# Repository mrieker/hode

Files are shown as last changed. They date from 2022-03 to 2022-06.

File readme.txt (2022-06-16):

        HODE 16-BIT TRANSISTOR COMPUTER

Website:  https://www.outerworldapps.com/hode

Uses a RaspberryPi for memory and IO (not needed for simulator).
Requires a Linux computer (x86 or raspi) to build software.
KiCad used to do PCB layouts.
Must have GNU C++ compiler, Java 8 or better dev kit.

Directories:

    asm      - cross assembler and linker
                $ make

    cc       - cross compiler
                $ make

    crtl     - C runtime library and example programs
                # make asm, cc, driver first
                $ cd library
                $ make
                $ cd ..
                $ make
                $ ./runit.sh circus.hex < test01.circ   ## runs in simlator (x86 or arm, no hode hardware required)
                $ ./runhw.sh circus.hex < test01.circ   ## runs on hode hardware that this raspi is plugged into

    de0      - DE0-Nano FPGA implementation (in verilog)
               requires de0-nano board, raspberry pi, kicads/de0raspi interconnect board
               use quartus to compile verilog in the de0 directory and program the de0-nano
               populate interconnect board with two 2x20 connectors and 26 33-ohm resistors
               plug raspi into the raspi connector and de0-nano gpio 1 into the de0 connector
               should be able to run any hode programs such as:

                # desktop calculator
                $ cd crtl
                $ ./runhw.sh calc.hex

                # rolling lights
                $ cd driver
                $ ./raspictl rollights.hex

    driver   - raspi control program and hardware test programs
                $ make
                $ cd km
                $ make                      ## on raspi only
                $ sudo insmod enabtsc.ko    ## on raspi only

                    note:  hexfile.hex is a placeholder for an actual hex file (see crtl directory)

                $ ./raspictl.armv7l       hexfile.hex   ## runs hexfile.hex on attached hode hardware
                                                        ## runs until hexfile.hex program calls exit()

                $ ./raspictl.armv7l -nohw hexfile.hex   ## simulator (no hode hardware required)

                $ ./raspictl.x86_64 -nohw hexfile.hex   ## simulator running on x86

    freecads - case component drawings

    goodpcbs - good pcb files (routing completed, including netlist and parts list files)

    kicads   - other kicad files
                de0raspi - interconnect for de0 nano and raspberry pi
                IOW56Paddle - IO-Warrior-56 paddles for board-level testing
                PowerDist - power distribution board - connects edge power to power supply

    modules  - board modules (verilog-like code)
                # make netgen first
                $ ./testmaster.sh   ## runs regression test scripts
                $ ./pcball.sh       ## generate raw .pcb files, need trace routing via kicad

    netgen   - java program to compile modules for simulation and pcb generation
                # make sure jninc_x86_64 or jninc_armv7l points to directory where jni.h is located
                $ make

For those makefiles that create objects and executables, they will create two versions,
one for x86_64 and one for armv7l, depending on which computer type they are run on.
Typically this is just done for the driver directory, once on a PC (creating the .x86_64
files) and once on a raspi (creating the .armv7l files).  The other directories are
typically only done on the PC but can be done on a raspi (either instead of or as well as).

HOW TO BUILD

    Each board takes a little under 1.5A at 5V * 9 boards = 13.5A + raspi (2.5A) = 16A.
    Get 40 2x20 stackable connectors (and a couple extra).
    Get 9 1x6 pin right angle connectors for power.

    Make the 4 paddles by making the circuit boards, populate with 10K 1/8 watt resistors,
    and get an IOWarrior-56 module for each.  Put a 2x20 stackable connector on each.
    Run drivers/iow56list.armv7l on the raspi to get the serial number for each one at a time.
    Label them A, C, I, D with little stickers and put the serial numbers in netgen/iow56sns.si.

    When populating the main boards, start with the diodes as they are uniquely marked.  Of course
    make sure the bands on the diodes match the bands on the board.  Next do the 2.7K resistors as
    they are among the diodes.  Next come the 680 resistors, they go near the transistor collector
    leads and then the 1K resistors that go near the transistor emitter leads.  Then do the bypass
    capacitors that go next to the transistor collector and emitter leads.  Finally put in the
    transistors then the edge connectors.

    When soldering the 2x20 stackable connectors to the boards, make sure they are mounted tightly
    on the boards so they will mate up when stacking the boards.  Be very careful when pulling the
    boards apart that you do not bend the pins on the stackable connectors.  Rock them little by
    little until each one comes apart.

    Optionally make an ledboard.pcb and populate.  It can be used for diagnostics as it shows the
    state of the bus connector pins.  It can be plugged into the other boards one at a time or in
    any combination.  It is not required for testing as the testing is all done via the paddles, but
    can make it easier to track down any problems.  Be careful to note 3 positions are populated
    with 2N3906s instead of the usual 2N3904s and the LEDs are reversed, as the _IR_WE, _PSW_IECLR,
    _PSW_REB signals are active low.

    Make a seqboard.pcb board and populate with diodes, resistors, capacitors, transistors, LEDs,
    connectors.  Connect to a variable power supply and turn slowly up to 5V, it should draw under
    1.5A.  Plug in the 4 paddles (actually just need C and I paddles).  Run the 'drivers/seqtester
    -cpuhz 200 -loop' script to test it.  The paddles are limited to 200Hz so that's why the '-cpuhz
    200' option is needed.

    Make a rasboard.pcb board and populate as usual.  You will also need a 2x20 connector for the
    raspi and a raspi 3 or 4 to plug into it.  The little 4x4 connector pins near the raspi connector
    jumpers the 5V power from the board's main power to the raspi.  With the jumpers removed, the
    raspi must be powered via its usual USB connector, otherwise the raspi will be powered from the
    board's 5V supply.  Once constructed, leave the raspi off the board and test it with a variable
    power supply like with the seqboard and see that it takes under 1.5A.  Then it should be ok to
    plug the raspi in.  You can use 7/16" spacers on 3/4" 4-40 screws to hold the raspi in place.
    Plug all 4 paddles into the edge of the rasboard and the USB cables into the raspi.  Run the
    'drivers/rastester.sh -cpuhz 200 -loop' script to test it.

    Plug the seqboard and rasboard together.  They should be oriented so the power connectors are at
    same position.  Run the 'drivers/raseqtest.sh -cpuhz 200 -loop' script to test it.  It assumes
    the 4 paddles are plugged in, if not, use the -nopads option on the command line and it will test
    as much as it can without it.  With -nopads, the two boards should run fast, so try leaving off the
    '-cpuhz 200' option.

    Make aluboards one at a time.  Jumper one as hi-byte and use 'drivers/alutester.sh -cpuhz 200 -loop
    hi' to test it with the 4 paddles.  Likewise make a lo-byte board and test it.

    Stack both aluboards and plug into the seqboard/rasboard stack.  Test with all 4 paddles plugged in
    to the stack and the raspi using the 'drivers/raseqtest.sh -alu -cpuhz 200 -loop' command.

    Finally come the register boards.  They can be tested individually with the 'drivers/regtester.sh 
    -cpuhz 200 -loop <nn>' script.  <nn> is 01, 23, 45, 67 depending on how the register board is
    jumpered.  When the board tests ok with the regtester script, it can be added to the seq/ras/alu
    stack and tested with 'drivers/raseqtest.sh -alu -cpuhz 200 -loop -reg<nn>' command.  Use a
    -reg01, -reg23, -reg45, -reg67 option for each register board you have put in the stack.

    When all 8 boards are completed, they can be tested at full speed with the 'drivers/raspictl.armv7l
    -randmem -mintimes' command.  It should run for days and days.  You can experiment with the -cpuhz
    option to specify different clocking frequencies.

    Then you can go to the crtl directory and run a program with the ./runhw.sh script, such as
    './runhw.sh printpi.hex' or './runhw.sh circus.hex < test01.circ'.

    Note that it doesn't matter what order the boards are stacked in, electrically speaking.  You can
    shuffle them around for testing and debugging.  But it is best to put the sequencer board on the
    front when you get it all working so you can see the blinking state LEDs.  If you make the optional
    LED board, it goes in front of the sequencer board and does not block any of the sequencer board's
    LEDs.

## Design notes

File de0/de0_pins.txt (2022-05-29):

    GPIO-0/JP1

    GPIO_0_IN0  A8   1   2  D3  GPIO_0_0
    GPIO_0_IN1  B8   3   4  C3  GPIO_0_1
    GPIO_0_2    A2   5   6  A3  GPIO_0_3
    GPIO_0_4    B3   7   8  B4  GPIO_0_5
    GPIO_0_6    A4   9  10  B5  GPIO_0_7
    VCC_SYS         11  12      GND
    GPIO_0_8    A5  13  14  D5  GPIO_0_9
    GPIO_0_10   B6  15  16  A6  GPIO_0_11
    GPIO_0_12   B7  17  18  D6  GPIO_0_13
    GPIO_0_14   A7  19  20  C6  GPIO_0_15
    GPIO_0_16   C8  21  22  E6  GPIO_0_17
    GPIO_0_18   E7  23  24  D8  GPIO_0_19
    GPIO_0_20   E8  25  26  F8  GPIO_0_21
    GPIO_0_22   F9  27  28  E9  GPIO_0_23
    VCC_3P3         29  30      GND
    GPIO_0_24   C9  31  32  D9  GPIO_0_25
    GPIO_0_26   E11 33  34  E11 GPIO_0_27
    GPIO_0_28   C11 35  36  B11 GPIO_0_29
    GPIO_0_30   A12 37  38  D11 GPIO_0_31
    GPIO_0_32   D12 39  40  B12 GPIO_0_33

    GPIO-1/JP2                                                      RASPI

            GPIO_1_IN0  T9   1   2  F13 GPIO_1_0    write           _qena   GPIO_21 40  39  GND
            GPIO_1_IN1  R9   3   4  T15 GPIO_1_1    m[15]           intrq   GPIO_20 38  37  GPIO_26 write
    _qena   GPIO_1_2    T14  5   6  T13 GPIO_1_3    m[09]           m[12]   GPIO_16 36  35  GPIO_19 m[15]
    intrq   GPIO_1_4    R13  7   8  T12 GPIO_1_5    m[02]                   GND     34  33  GPIO_13 m[09]
    m[12]   GPIO_1_6    R12  9  10  T11 GPIO_1_7    m[01]           m[08]   GPIO_12 32  31  GPIO_6  m[02]
            VCC_SYS         11  12      GND                                 GND     30  29  GPIO_5  m[01]
    m[08]   GPIO_1_8    T10 13  14  R11 GPIO_1_9                            ID_SC   28  27  ID_SD
    m[03]   GPIO_1_10   P11 15  16  R10 GPIO_1_11                   m[03]   GPIO_7  26  25  GND
    m[04]   GPIO_1_12   N12 17  18  P9  GPIO_1_13   m[07]           m[04]   GPIO_8  24  23  GPIO_11 m[07]
    read    GPIO_1_14   N9  19  20  N11 GPIO_1_15   m[05]           read    GPIO_25 22  21  GPIO_9  m[05]
            GPIO_1_16   L16 21  22  K16 GPIO_1_17   m[06]                   GND     20  19  GPIO_10 m[06]
    halt    GPIO_1_18   R16 23  24  L15 GPIO_1_19   dena            halt    GPIO_24 18  17  3.3V
    word    GPIO_1_20   P15 25  26  P16 GPIO_1_21   flag            word    GPIO_23 16  15  GPIO_22 dena
            GPIO_1_22   R14 27  28  N16 GPIO_1_23   m[13]                   GND     14  13  GPIO_27 flag
            VCC_3P3         29  30      GND                         m[14]   GPIO_18 12  11  GPIO_17 m[13]
    m[14]   GPIO_1_24   N15 31  32  P14 GPIO_1_25                   m[11]   GPIO_15 10   9  GND
    m[11]   GPIO_1_26   L14 33  34  N14 GPIO_1_27   m[00]           m[10]   GPIO_14  8   7  GPIO_4  m[00]
    m[10]   GPIO_1_28   M10 35  36  L13 GPIO_1_29   reset                   GND      6   5  GPIO_3  reset
            GPIO_1_30   J16 37  38  K15 GPIO_1_31   clock                   5V       4   3  GPIO_2  clock
            GPIO_1_32   J13 39  40  J14 GPIO_1_33                           5V       2   1  3.3V

                                         CLK    CS   RES   GND   3.3
                                           *     *     *     *     *
                                           6     7     8     9    10

                                                    OLIMEX
                                                  ENC28J60-H

                                           5     4     3     2     1
                                           *     *     *     *     *
                                         INT   WOL    SO    SI   SCK

                                      PIN_D9   E10   B11   D11   B12
                                    GPIO_025   027   029   031   033
                GND                GND   INT   CLK    CS   RES    COMRCV
 2               12                 30    32    34    36    38    40
 *                *                  *     *     *     *     *     *

 *                *                  *     *     *     *     *     *
 1               11                 29    31    33    35    37    39
                +5V               +3.3   WOL    SO    SI   SCK    COMXMT
                                    GPIO_024   026   028   030   032
                                      PIN_C9   E11   C11   A12   D12

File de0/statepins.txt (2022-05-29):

halt state pin:

    fetch1q -> STATES[07] -> PIN_B5 -> GPIO_0_7  -> pin 10
    fetch2q -> STATES[08] -> PIN_A5 -> GPIO_0_8  -> pin 13
    halt1q  -> STATES[17] -> PIN_E6 -> GPIO_0_17 -> pin 22

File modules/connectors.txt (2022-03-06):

    abbus: Conn
         1  oo      abus[00]    bbus[00]
         3  oo      abus[08]    bbus[08]
         5  go                  abus[01]
         7  oo      bbus[01]    abus[09]
         9  go                  bbus[09]
        11  oo      abus[02]    bbus[02]
        13  go                  abus[10]
        15  oo      bbus[10]    abus[03]
        17  go                  bbus[03]
        19  oo      abus[11]    bbus[11]
        21  oo      abus[04]    bbus[04]
        23  go                  abus[12]
        25  oo      bbus[12]    abus[05]
        27  go                  bbus[05]
        29  oo      abus[13]    bbus[13]
        31  go                  abus[06]
        33  oo      bbus[06]    abus[14]
        35  go                  bbus[14]
        37  oo      abus[07]    bbus[07]
        39  oo      abus[15]    bbus[15]

    irbus: Conn
         1  oo       ir[00]     _ir[00]
         3  oo       ir[01]     _ir[01]
         5  go                   ir[02]
         7  oo      _ir[02]      ir[03]
         9  go                  _ir[03]
        11  oo       ir[04]     _ir[04]
        13  go                   ir[05]
        15  oo      _ir[05]      ir[06]
        17  go                  _ir[06]
        19  oo       ir[07]     _ir[07]
        21  oo       ir[08]     _ir[08]
        23  go                   ir[09]
        25  oo      _ir[09]      ir[10]
        27  go                  _ir[10]
        29  oo       ir[11]     _ir[11]
        31  go                   ir[12]
        33  oo      _ir[12]      ir[13]
        35  go                  _ir[13]
        37  oo       ir[14]     _ir[14]
        39  oo       ir[15]     _ir[15]

    dbus: Conn
         1  oo      dbus[15]    dbus[07]
         3  oo      dbus[14]    dbus[06]
         5  go                  dbus[13]
         7  oo      dbus[05]    dbus[12]
         9  go                  dbus[04]
        11  oo      dbus[11]    dbus[03]
        13  go                  dbus[10]
        15  oo      dbus[02]    dbus[09]
        17  go                  dbus[01]
        19  oo      dbus[08]    dbus[00]

        21  ii      I21:rawcin      # carry into alu[00]
                    I22:rawcmid     # carry into alu[08]

        23  go      O24:rawcmid     # carry outof alu[07]

        25  oo      O25:rawcout     # carry outof alu[15]
                    O26:rawvout     # carry outof alu[14]

        27  gi      I28:rawshrmid   # shift right into alu[07]

        29  ii      I29:rawshrin    # shift right into alu[15]
                    I30:not used

        31  go      O32:rawshrout   # shift right outof alu[00]

        33  oi      O33:rawshrmid   # shift right outof alu[08]
        35  gi
        37  ii
        39  ii

    ctla: Conn
         1  ii      I1:  IRQ            I2:  PSW_IE
         3  ii      I3:  PSW_BT         I4:  RESET
         5  gi                          I6:  CLK2
         7  oo      O7:                 O8:  MEM_REB
         9  go                          O10: PSW_ALUWE
        11  oo      O11: ALU_IRFC       O12: GPRS_REB
        13  go                          O14: BMUX_IRBROF
        15  oo      O15: GPRS_WED       O16: MEM_READ
        17  go                          O18: PSW_WE
        19  oo      O19: HALT           O20: GPRS_REA
        21  oo      O21:                O22: GPRS_RED2B
        23  go                          O24: ALU_BONLY
        25  oo      O25: BMUX_IRLSOF    O26: _PSW_RE
        27  go                          O28: BMUX_CON__4
        29  oo      O29: MEM_WORD       O30: ALU_ADD
        31  go                          O32: GPRS_WE7
        33  oo      O33: GPRS_REA7      O34: BMUX_CON_2
        35  go                          O36: _IR_WE
        37  oo      O37:                O38: BMUX_CON_0
        39  oo      O39: MEM_WRITE      O40: _PSW_IECLR

    gpio: Conn  (looking at backside of PI)
                        5v   02 01  3.3v
                        5v   04 03  gpio 02     > CLOCK
                        gnd  06 05  gpio 03     > RESET
        data[10]    gpio 14  08 07  gpio 04     data[00]
        data[11]    gpio 15  10 09  gnd
        data[14]    gpio 18  12 11  gpio 17     data[13]
                        gnd  14 13  gpio 27
          WORD >    gpio 23  16 15  gpio 22     > DENA
          HALT >    gpio 24  18 17  3.3v
                        gnd  20 19  gpio 10     data[06]
          READ >    gpio 25  22 21  gpio 09     data[05]
        data[04]    gpio 08  24 23  gpio 11     data[07]
        data[03]    gpio 07  26 25  gnd
                    gpio 01  28 27  gpio 00
                        gnd  30 29  gpio 05     data[01]
        data[08]    gpio 12  32 31  gpio 06     data[02]
                        gnd  34 33  gpio 13     data[09]
        data[12]    gpio 16  36 35  gpio 19     data[15]
           IRQ <    gpio 20  38 37  gpio 26     < WRITE
          QENA <    gpio 21  40 39  gnd

    power: Conn
                v v v g g g ()

ALUBOARD:

        CTLA
    ABBUS   DBUS
        IBUS

RASBOARD,REGBOARD:

        IBUS
    DBUS    ABBUS
        CTLA

SEQBOARD,LEDBOARD:

        ABBUS
    IBUS    CBUS
        DBUS

                            pin1: 10.7,0.2
                pin40: 8.8,0.3

pin1: 0.2,8.8                       pin40: 19.2,8.8
    pin40: 0.3,10.7                     pin1: 19.3,10.7

                            pin40: 10.7,19.2
                pin1: 8.8,19.3

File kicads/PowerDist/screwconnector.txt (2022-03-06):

https://www.mouser.com/ProductDetail/Molex/38700-7302?qs=SWvc%2Fhn7BQxFykf9e2oDGA%3D%3D
https://www.mouser.com/datasheet/2/276/0387007302_TERMINAL_BLOCKS-138371.pdf
https://www.molex.com/pdm_docs/sd/387007302_sd.pdf

dy  = 0.325

ycenter = 0.5

y1 = 0.5 - 0.1625 = 0.3375
y2 = 0.5 + 0.1625 = 0.6625

    6625
    3375
    ----
    3250

0.364 - 0.311 = 0.053" diam hole
              = 1.346 mm

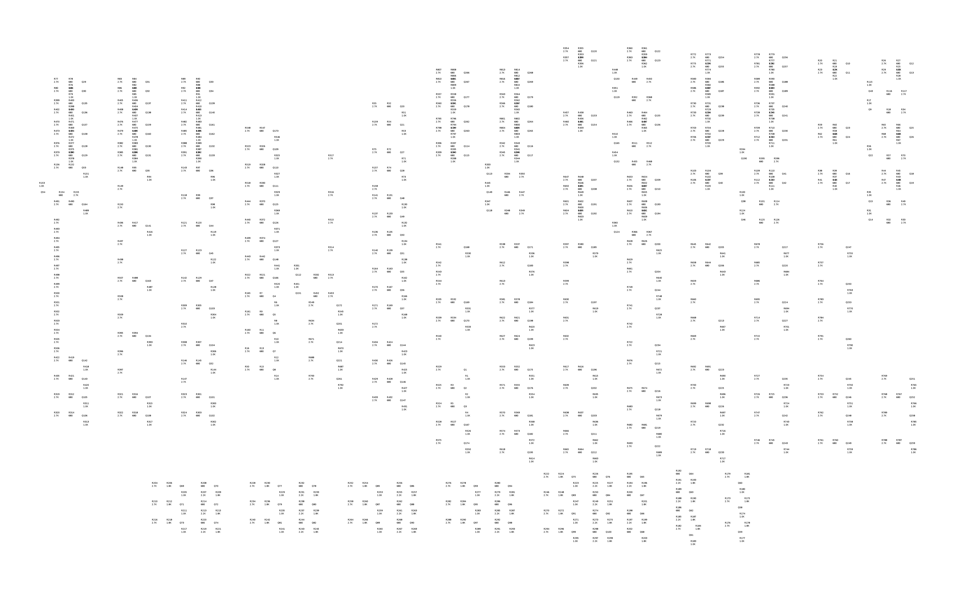
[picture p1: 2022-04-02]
goodpcbs/rasboard.png

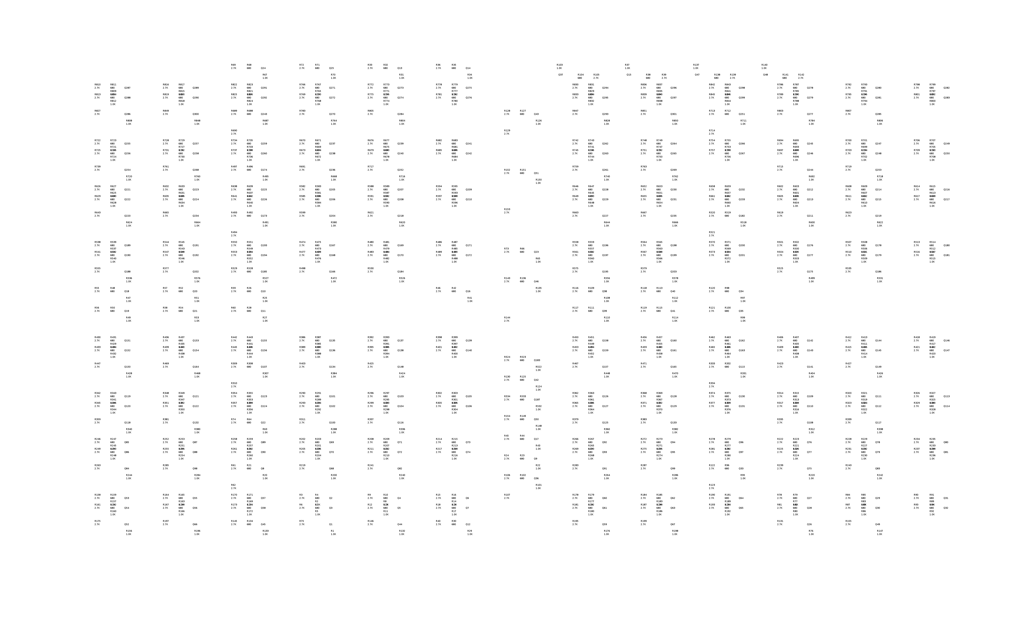
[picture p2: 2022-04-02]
goodpcbs/regboard.png

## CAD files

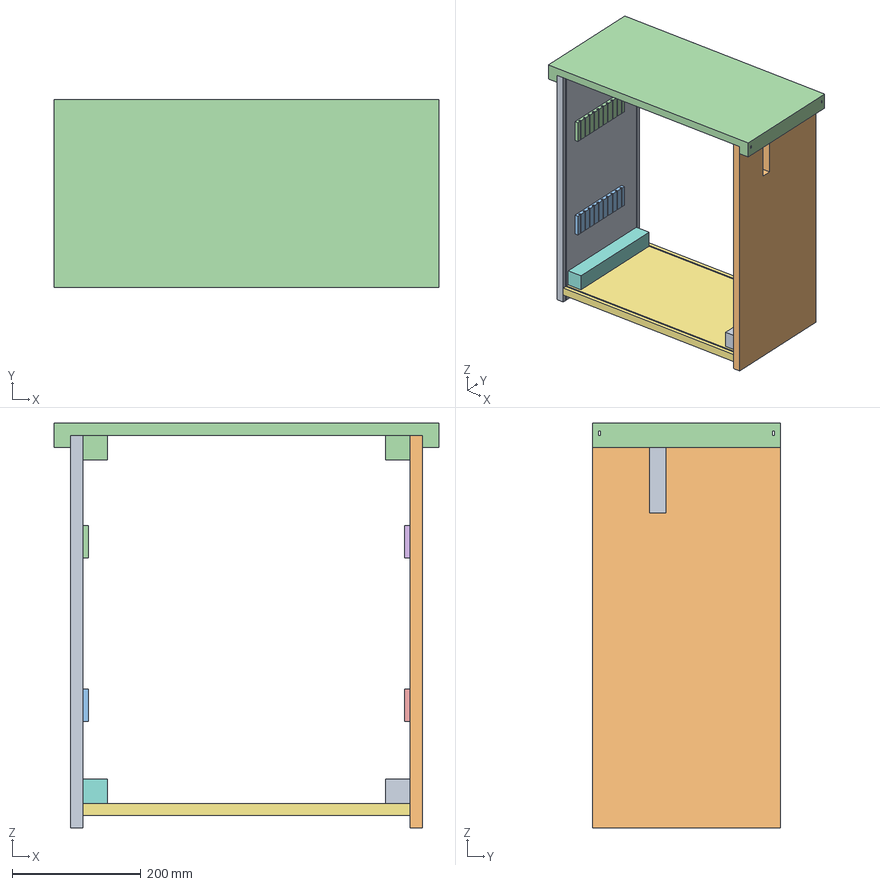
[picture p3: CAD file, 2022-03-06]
freecads/caseassy.FCStd
596.9 x 292.1 x 628.7 mm
leftpanel_001
rightpanel_001
slots_loleft
slots_upleft
slots_loright
slots_upright
botpanel_001
botblock_left
botblock_right
topblock_left
topblock_right
toppanel_001

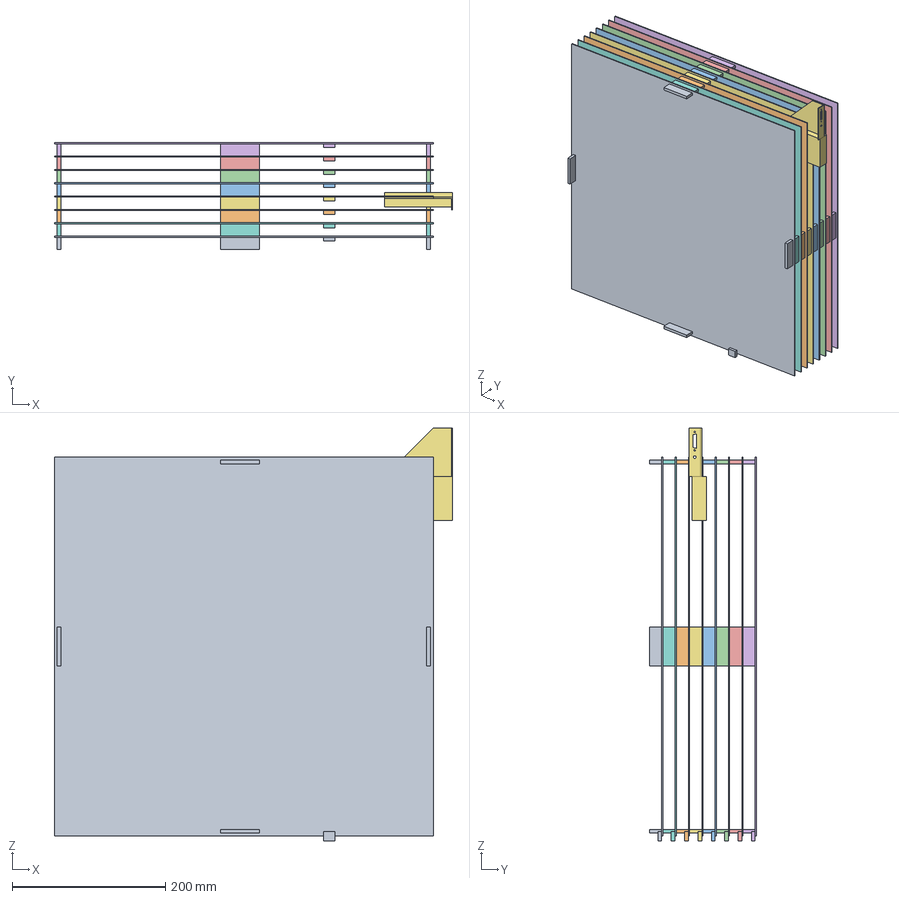
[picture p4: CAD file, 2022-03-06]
freecads/circbdassy.FCStd
520.7 x 139.7 x 539.8 mm
circboard_seq
circboard_alulo
circboard_reg01
circboard_reg23
circboard_reg45
circboard_reg67
raspiboard_001
circboard_aluhi

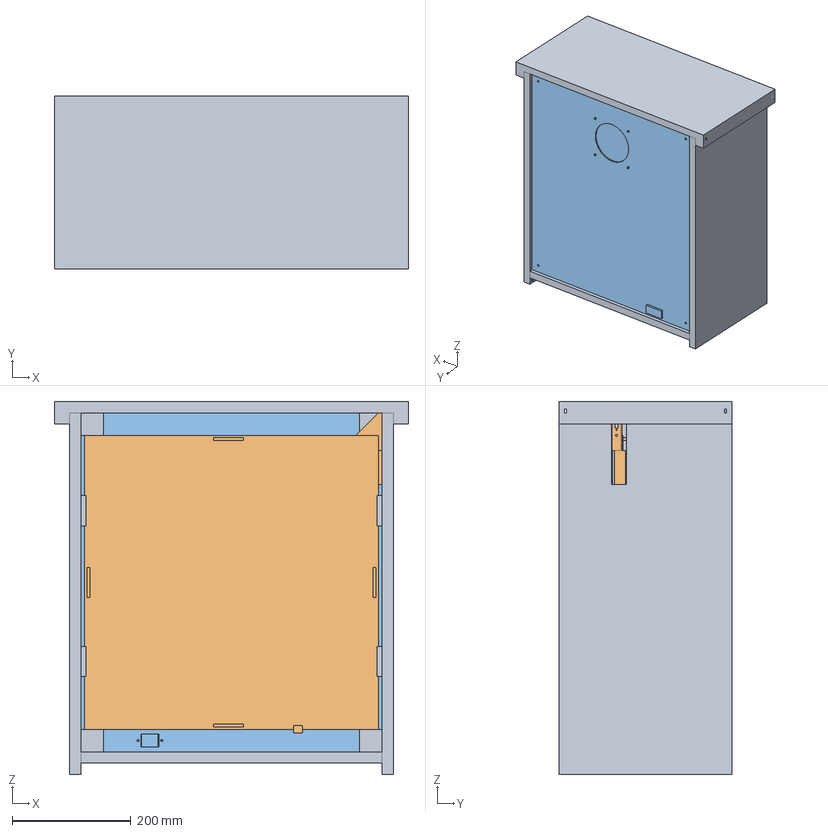
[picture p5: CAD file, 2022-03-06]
freecads/wholething.FCStd
596.9 x 292.1 x 628.7 mm
caseassy_001
circbdassy_001
backpanandacc_001

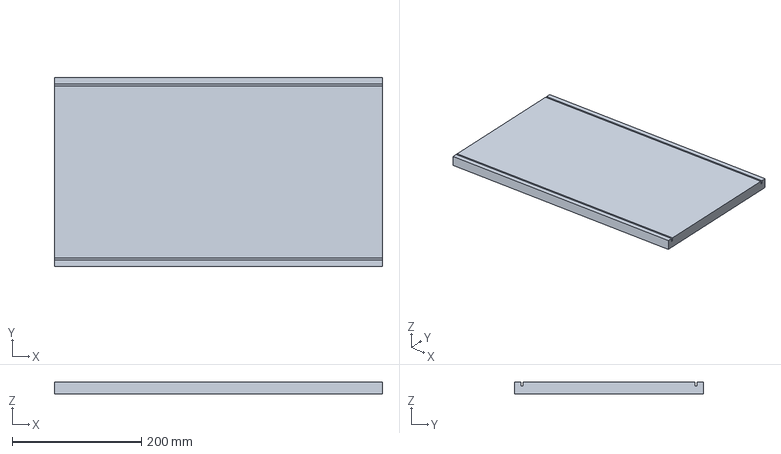
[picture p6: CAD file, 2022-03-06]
freecads/botpanel.FCStd
508.0 x 292.1 x 19.0 mm

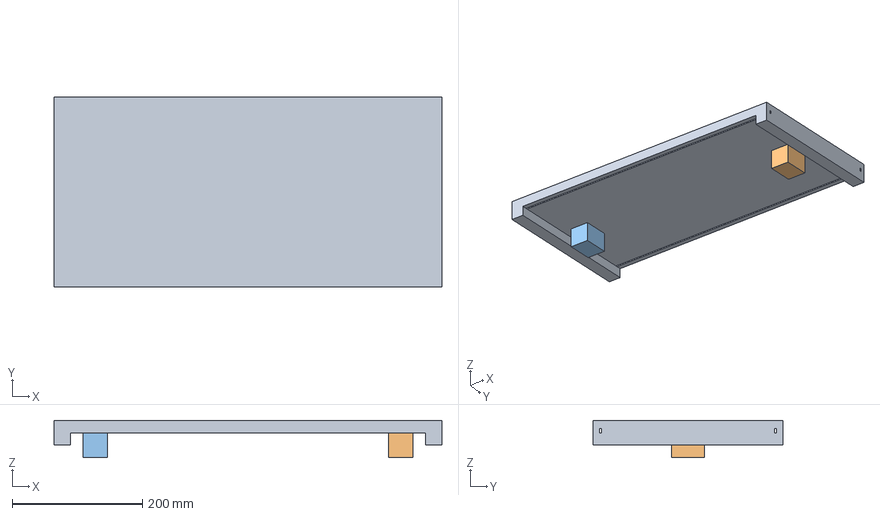
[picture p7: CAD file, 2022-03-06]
freecads/toppanel.FCStd
596.9 x 292.1 x 57.2 mm
topblock_right
topblock_left

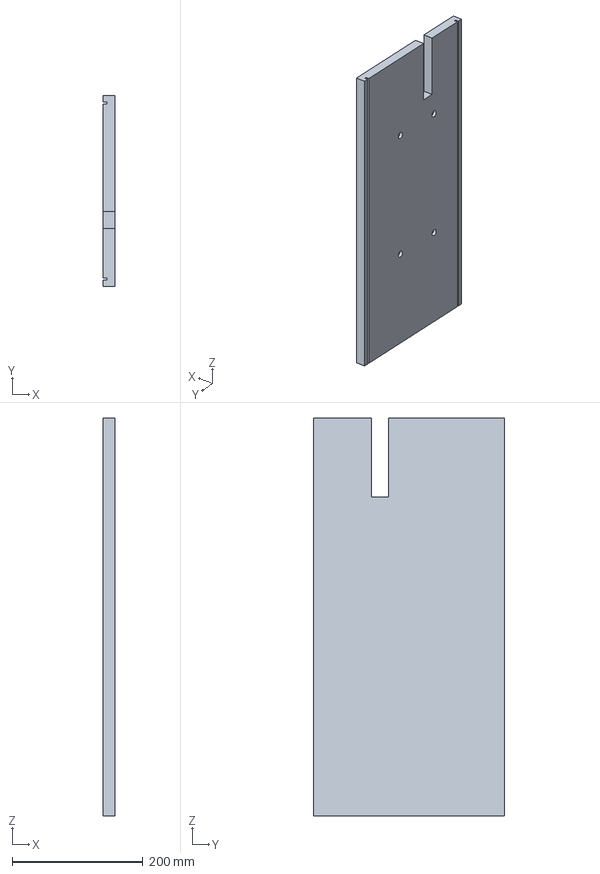
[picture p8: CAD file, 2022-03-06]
freecads/rightpanel.FCStd
19.1 x 292.1 x 609.6 mm

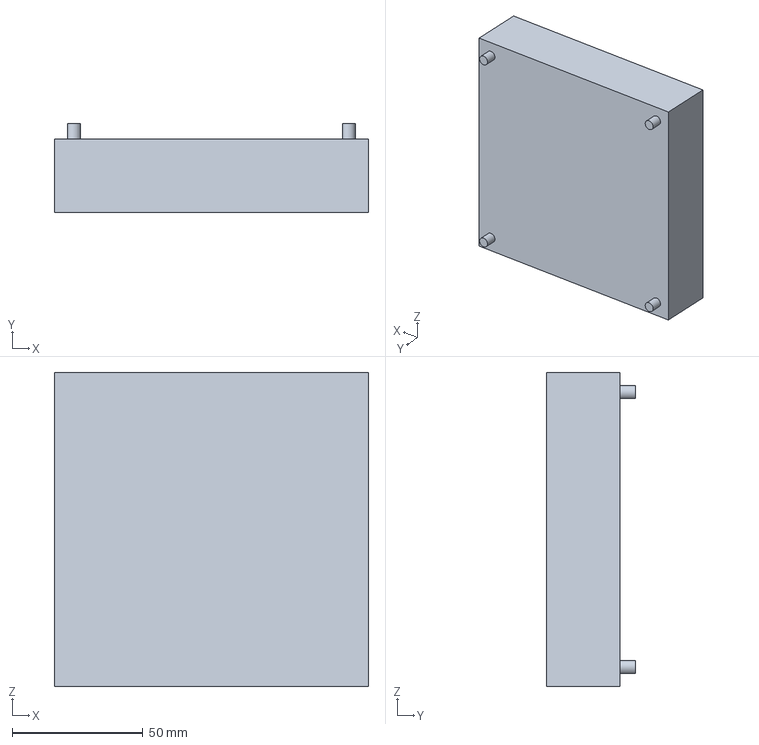
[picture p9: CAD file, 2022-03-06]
freecads/120mmfan.FCStd
120.0 x 34.0 x 120.0 mm

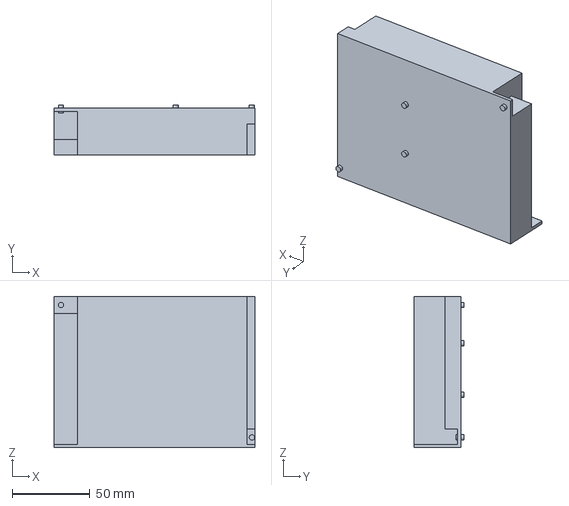
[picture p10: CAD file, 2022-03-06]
freecads/powersup.FCStd
129.0 x 32.0 x 97.0 mm

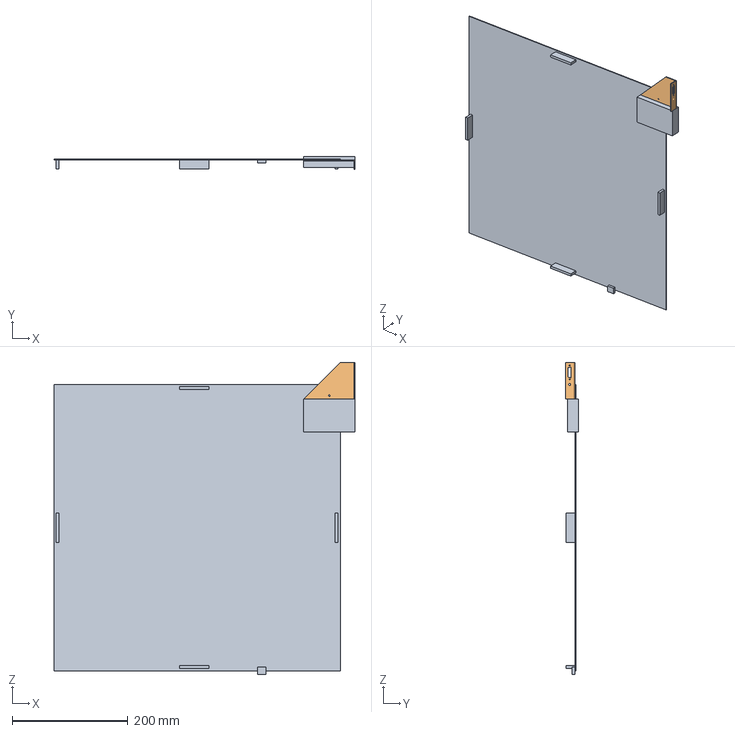
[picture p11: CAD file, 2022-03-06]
freecads/raspiboard.FCStd
520.7 x 23.2 x 539.7 mm
raspi_body
raspibrkt_001

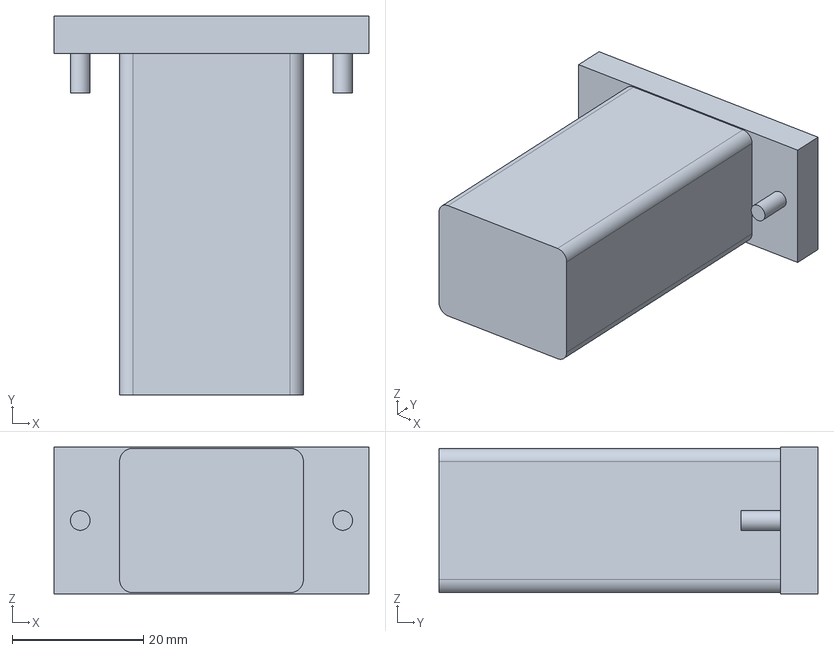
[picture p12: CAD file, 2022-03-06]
freecads/acpwrcon.FCStd
48.0 x 57.7 x 22.4 mm

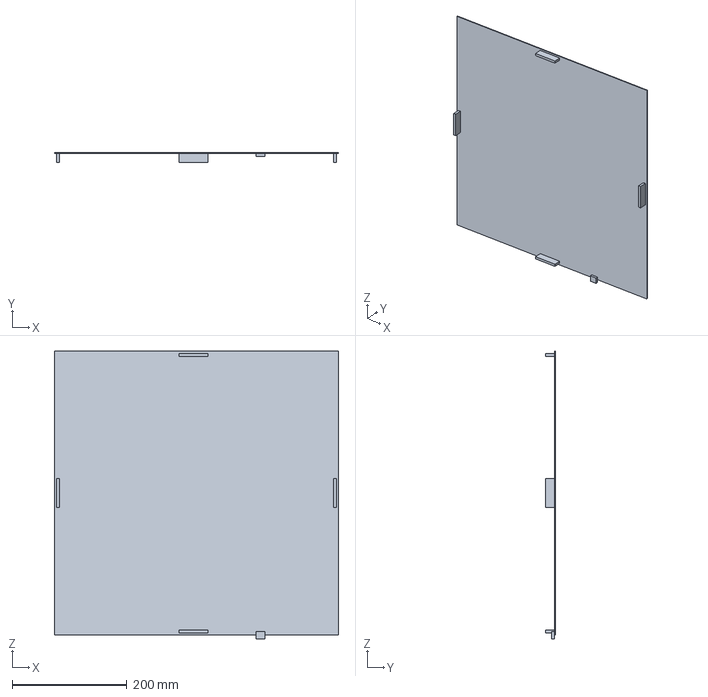
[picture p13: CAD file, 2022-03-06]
freecads/circboard.FCStd
495.3 x 17.5 x 501.6 mm

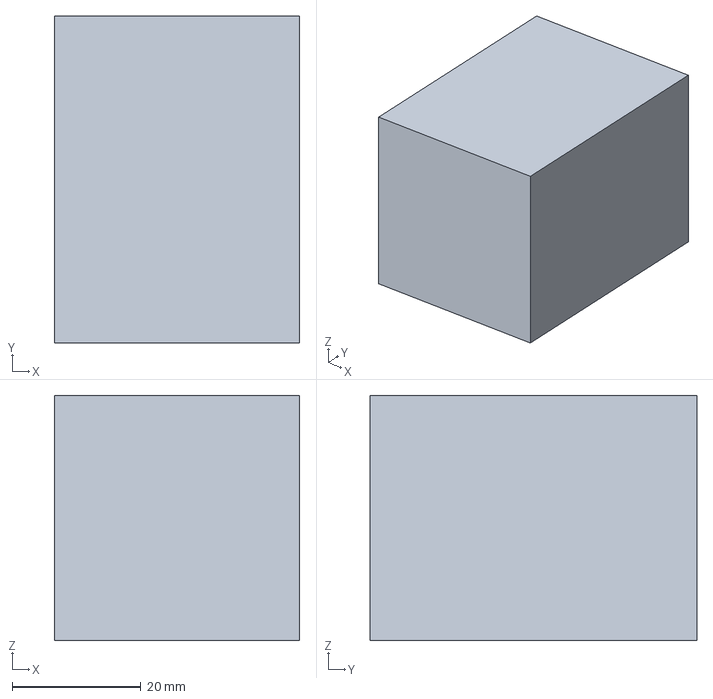
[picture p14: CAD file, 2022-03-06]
freecads/topblock.FCStd
38.1 x 50.8 x 38.1 mm

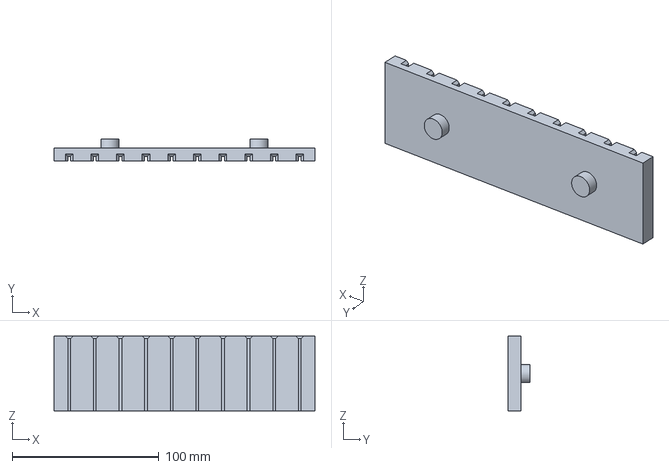
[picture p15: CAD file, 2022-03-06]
freecads/slots.FCStd
177.8 x 15.1 x 50.8 mm

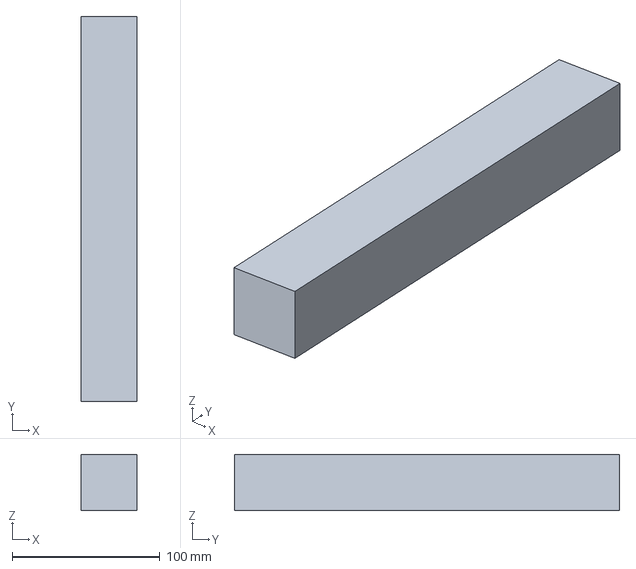
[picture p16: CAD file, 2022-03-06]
freecads/botblock.FCStd
38.1 x 260.4 x 38.1 mm

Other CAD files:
freecads/leftpanel.FCStd
freecads/backpanandacc.FCStd
freecads/raspibrkt.FCStd
freecads/backpanel.FCStd

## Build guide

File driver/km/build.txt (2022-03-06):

# make sure running latest kernel so installing headers will match version
apt-get update
apt-get upgrade

# install latest headers
apt-get install raspberrypi-kernel-headers

# compile and load
make
insmod enabtsc.ko

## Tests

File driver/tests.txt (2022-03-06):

# all tests require
sudo insmod km/enabtsc.ko
. ./iow56sns.si

# worst-case timing
./raspictl.armv7l -oddok wc2loop.hex

# worst-case timing and print states
./raspictl.armv7l -oddok -printstate -cpuhz 10000 wc2loop.hex

# random number test for R4,R5,R6,R7
./raspictl.armv7l -printstate randtest.hex

# random number test for R4,R5,R6,R7
#  print cycles every minute
#  run at 72KHz
./raspictl.armv7l randtest.hex -mintimes -cpuhz 72000

# continuously write zeroes to R2 (uses paddles)
sudo -E ./writezeroestorn.armv7l 2

# test board stack of seq,ras,aluhi,alulo,reg23,reg45,reg67 (uses paddles)
./raseqtest.sh -alu -cpuhz 200 -nopads -reg23 -reg45 -reg67

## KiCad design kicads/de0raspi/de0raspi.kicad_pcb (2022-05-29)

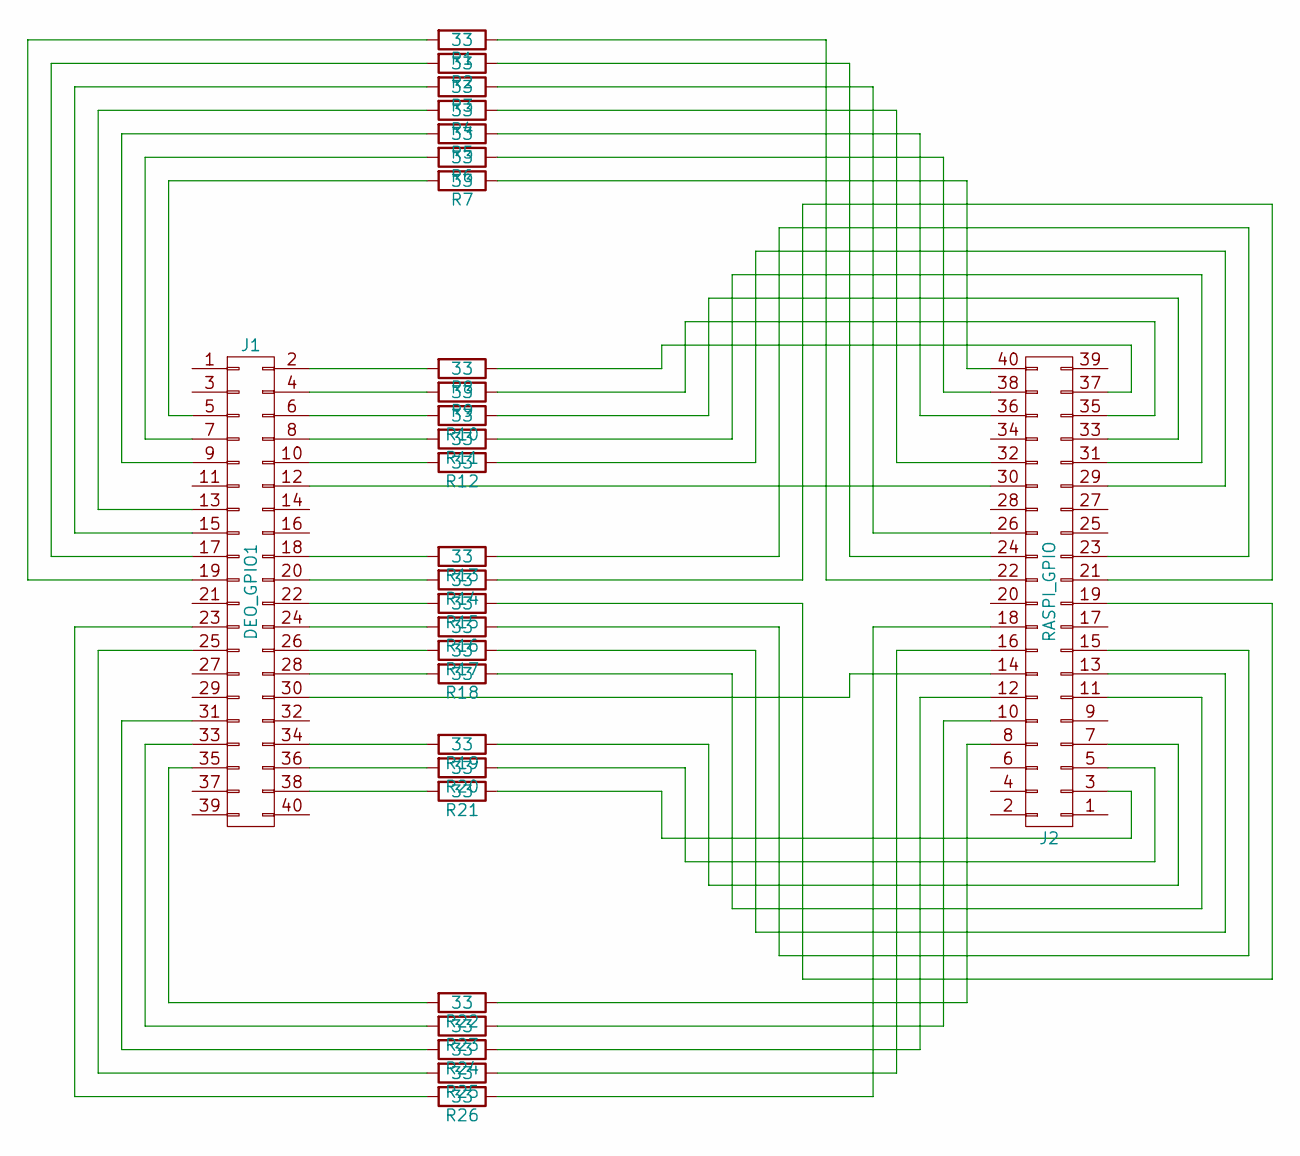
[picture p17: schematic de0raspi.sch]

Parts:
J1: DEO_GPIO1; Pin_Header_Straight_2x20_Pitch2.54mm
J2: RASPI_GPIO; Pin_Header_Straight_2x20_Pitch2.54mm
R1, R2, R3, R4, R5, R6, R7, R8, R9, R10, R11, R12, R13, R14, R15, R16, R17, R18, R19, R20, R21, R22, R23, R24, R25, R26: 33; R_Axial_DIN0204_L3.6mm_D1.6mm_P5.08mm_Horizontal

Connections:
unnamed: J1.2, R8.2
unnamed: J1.4, R9.2
unnamed: J1.5, R7.2
unnamed: J1.6, R10.2
unnamed: J1.7, R6.2
unnamed: J1.8, R11.2
unnamed: J1.9, R5.2
unnamed: J1.10, R12.2
unnamed: J1.12, J2.30
unnamed: J1.13, R4.2
unnamed: J1.15, R3.2
unnamed: J1.17, R2.2
unnamed: J1.18, R13.2
unnamed: J1.19, R1.2
unnamed: J1.20, R14.2
unnamed: J1.22, R15.2
unnamed: J1.23, R26.2
unnamed: J1.24, R16.2
unnamed: J1.25, R25.2
unnamed: J1.26, R17.2
unnamed: J1.28, R18.2
unnamed: J1.30, J2.14
unnamed: J1.31, R24.2
unnamed: J1.33, R23.2
unnamed: J1.34, R19.2
unnamed: J1.35, R22.2
unnamed: J1.36, R20.2
unnamed: J1.38, R21.2
unnamed: J2.3, R21.1
unnamed: J2.5, R20.1
unnamed: J2.7, R19.1
unnamed: J2.8, R22.1
unnamed: J2.10, R23.1
unnamed: J2.11, R18.1
unnamed: J2.12, R24.1
unnamed: J2.13, R17.1
unnamed: J2.15, R16.1
unnamed: J2.16, R25.1
unnamed: J2.18, R26.1
unnamed: J2.19, R15.1
unnamed: J2.21, R14.1
unnamed: J2.22, R1.1
unnamed: J2.23, R13.1
unnamed: J2.24, R2.1
unnamed: J2.26, R3.1
unnamed: J2.29, R12.1
unnamed: J2.31, R11.1
unnamed: J2.32, R4.1
unnamed: J2.33, R10.1
unnamed: J2.35, R9.1
unnamed: J2.36, R5.1
unnamed: J2.37, R8.1
unnamed: J2.38, R6.1
unnamed: J2.40, R7.1

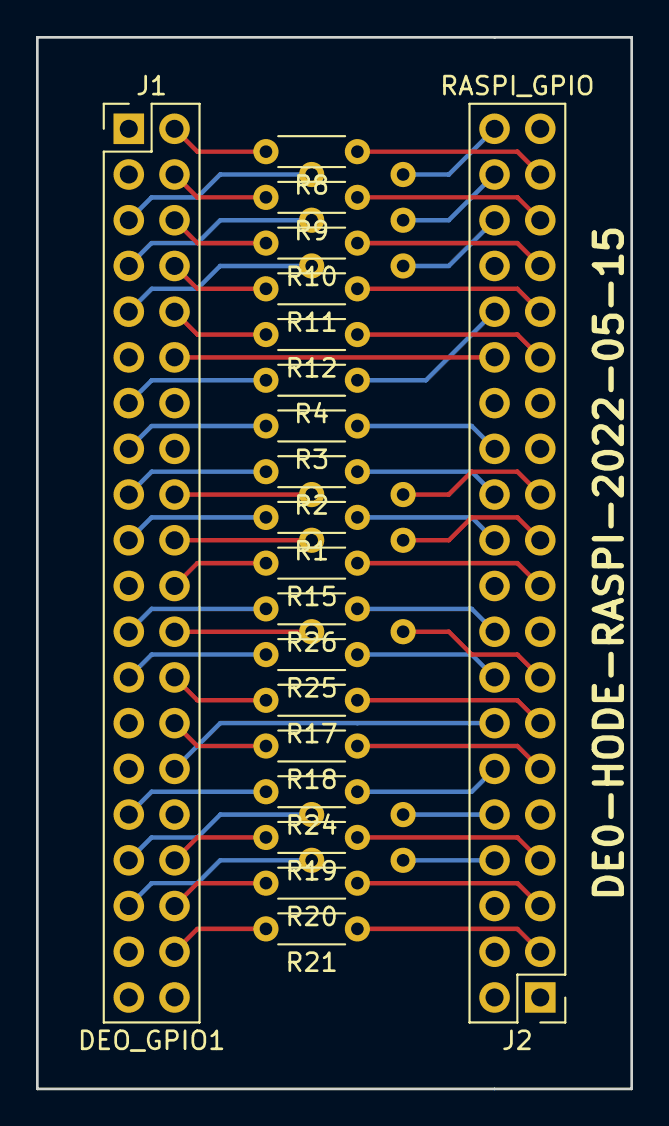
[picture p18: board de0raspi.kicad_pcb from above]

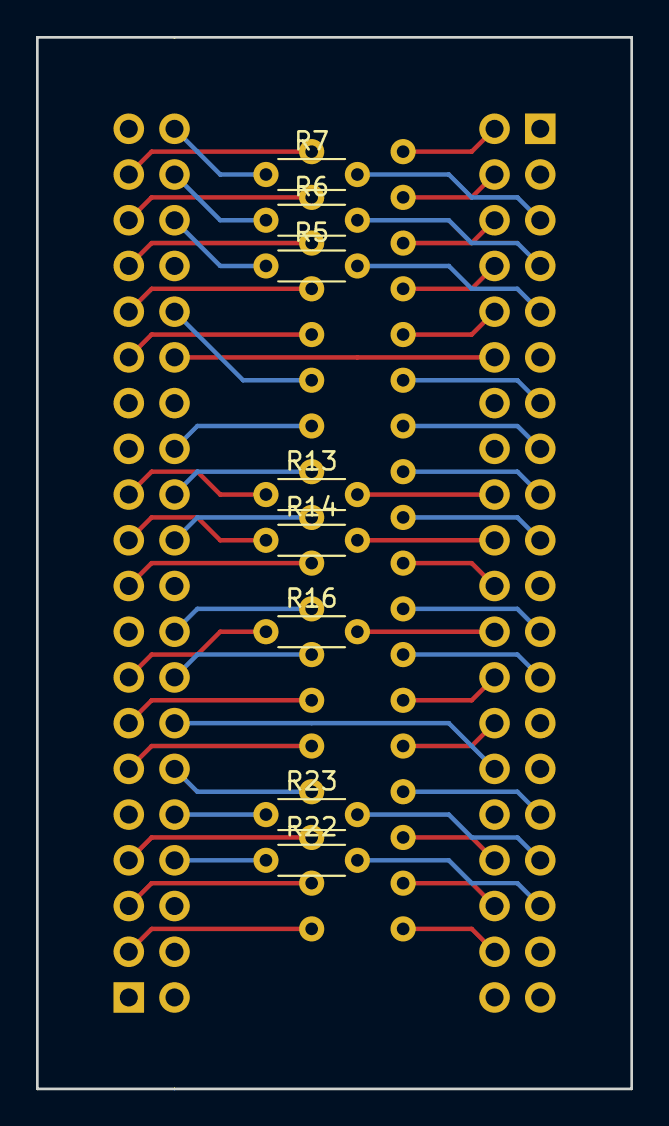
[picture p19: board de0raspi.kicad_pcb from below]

Board: 2 copper layers, 33.0 x 58.4 mm, 28 parts (8 on the bottom side), 54 nets.

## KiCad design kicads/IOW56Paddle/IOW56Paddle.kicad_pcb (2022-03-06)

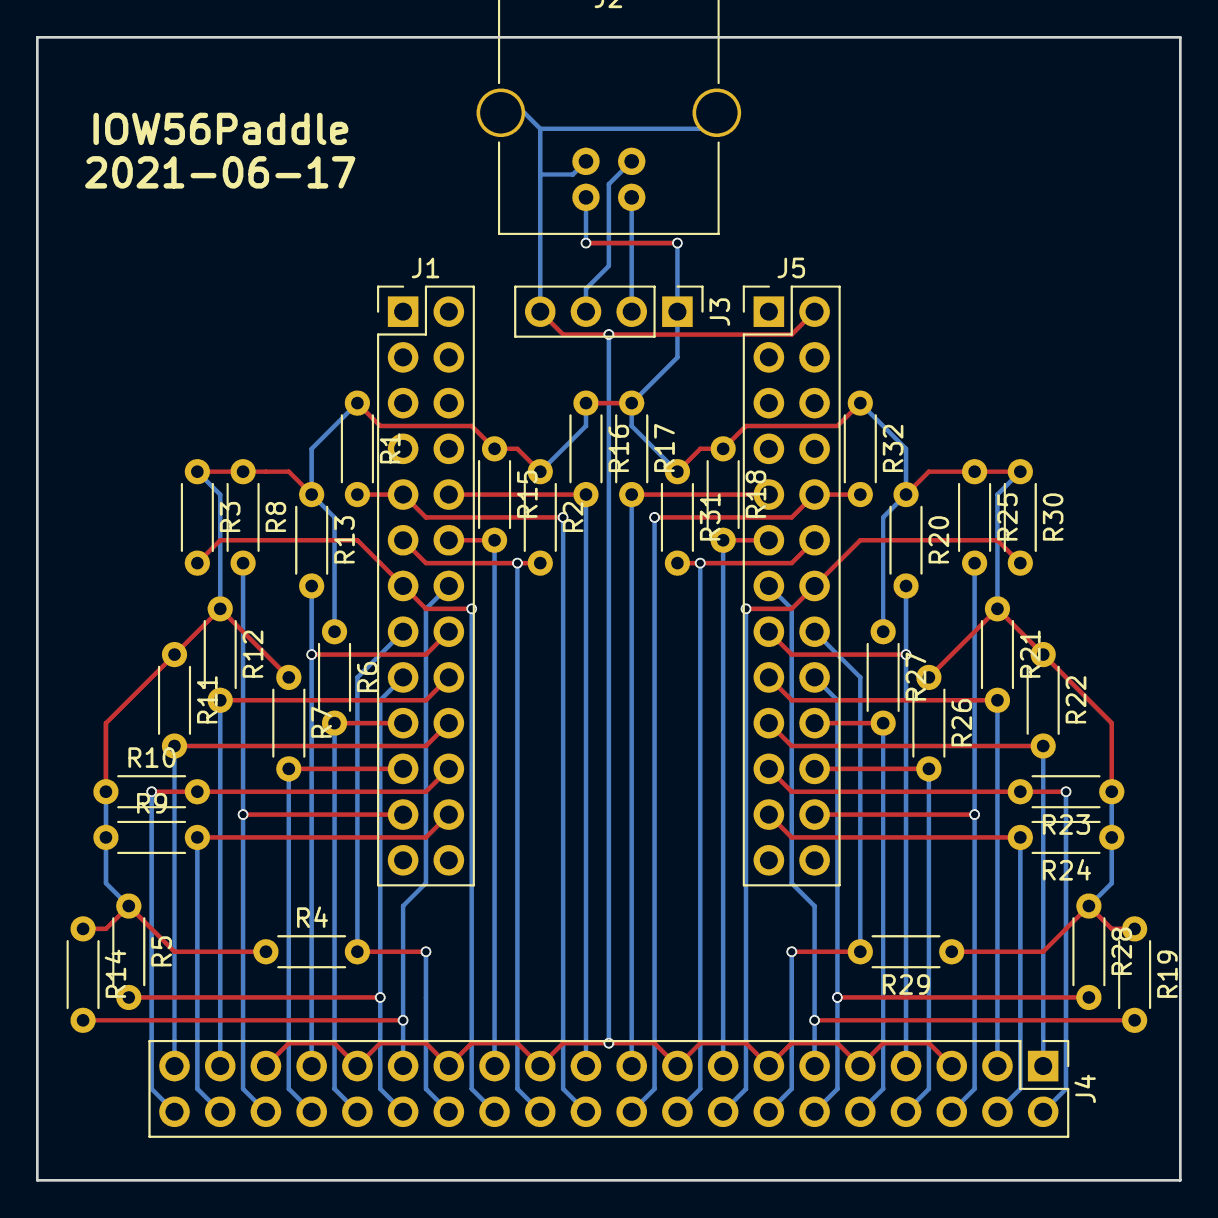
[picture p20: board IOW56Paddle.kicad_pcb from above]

Board: 2 copper layers, 63.5 x 63.5 mm, 37 parts (0 on the bottom side), 36 nets.

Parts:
J1, J5: CONN_02X13; Pin_Header_Straight_2x13_Pitch2.54mm
J2: USB_B
J3: CONN_01X04; Pin_Header_Straight_1x04_Pitch2.54mm
J4: CONN_02X20; Pin_Header_Straight_2x20_Pitch2.54mm
R1, R2, R3, R4, R5, R6, R7, R8, R9, R10, R11, R12, R13, R14, R15, R16, R17, R18, R19, R20, R21, R22, R23, R24, R25, R26, R27, R28, R29, R30, R31, R32: R; R_Axial_DIN0204_L3.6mm_D1.6mm_P5.08mm_Horizontal

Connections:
GND: J2.4, J2.5, J3.4, J4.5, J4.9, J4.13, J4.17, J4.23, J4.27, J4.31, J4.35, J5.2
unnamed: J1.9, J4.22, R1.2
unnamed: J1.10, J4.21, R16.2
unnamed: J1.11, J4.24, R2.2
unnamed: J1.12, J4.25, R15.2
unnamed: J1.13, J4.26, R3.2
unnamed: J1.14, J4.29, R14.2
unnamed: J1.15, J4.28, R4.2
unnamed: J1.16, J4.33, R13.2
unnamed: J1.17, J4.30, R5.2
unnamed: J1.18, J4.37, R12.2
unnamed: J1.19, J4.32, R6.2
unnamed: J1.20, J4.39, R11.2
unnamed: J1.21, J4.34, R7.2
unnamed: J1.22, J4.40, R10.2
unnamed: J1.23, J4.36, R8.2
unnamed: J1.24, J4.38, R9.2
unnamed: J2.1, J3.1, R1.1, R2.1, R3.1, R4.1, R5.1, R6.1, R7.1, R8.1, R9.1, R10.1, R11.1, R12.1, R13.1, R14.1, R15.1, R16.1, R17.1, R18.1, R19.1, R20.1, R21.1, R22.1, R23.1, R24.1, R25.1, R26.1, R27.1, R28.1, R29.1, R30.1, R31.1, R32.1
unnamed: J2.2, J3.2
unnamed: J2.3, J3.3
unnamed: J4.1, J5.19, R22.2
unnamed: J4.2, J5.21, R23.2
unnamed: J4.3, J5.17, R21.2
unnamed: J4.4, J5.23, R24.2
unnamed: J4.6, J5.24, R25.2
unnamed: J4.7, J5.15, R20.2
unnamed: J4.8, J5.22, R26.2
unnamed: J4.10, J5.20, R27.2
unnamed: J4.11, J5.13, R19.2
unnamed: J4.12, J5.18, R28.2
unnamed: J4.14, J5.16, R29.2
unnamed: J4.15, J5.11, R18.2
unnamed: J4.16, J5.14, R30.2
unnamed: J4.18, J5.12, R31.2
unnamed: J4.19, J5.9, R17.2
unnamed: J4.20, J5.10, R32.2

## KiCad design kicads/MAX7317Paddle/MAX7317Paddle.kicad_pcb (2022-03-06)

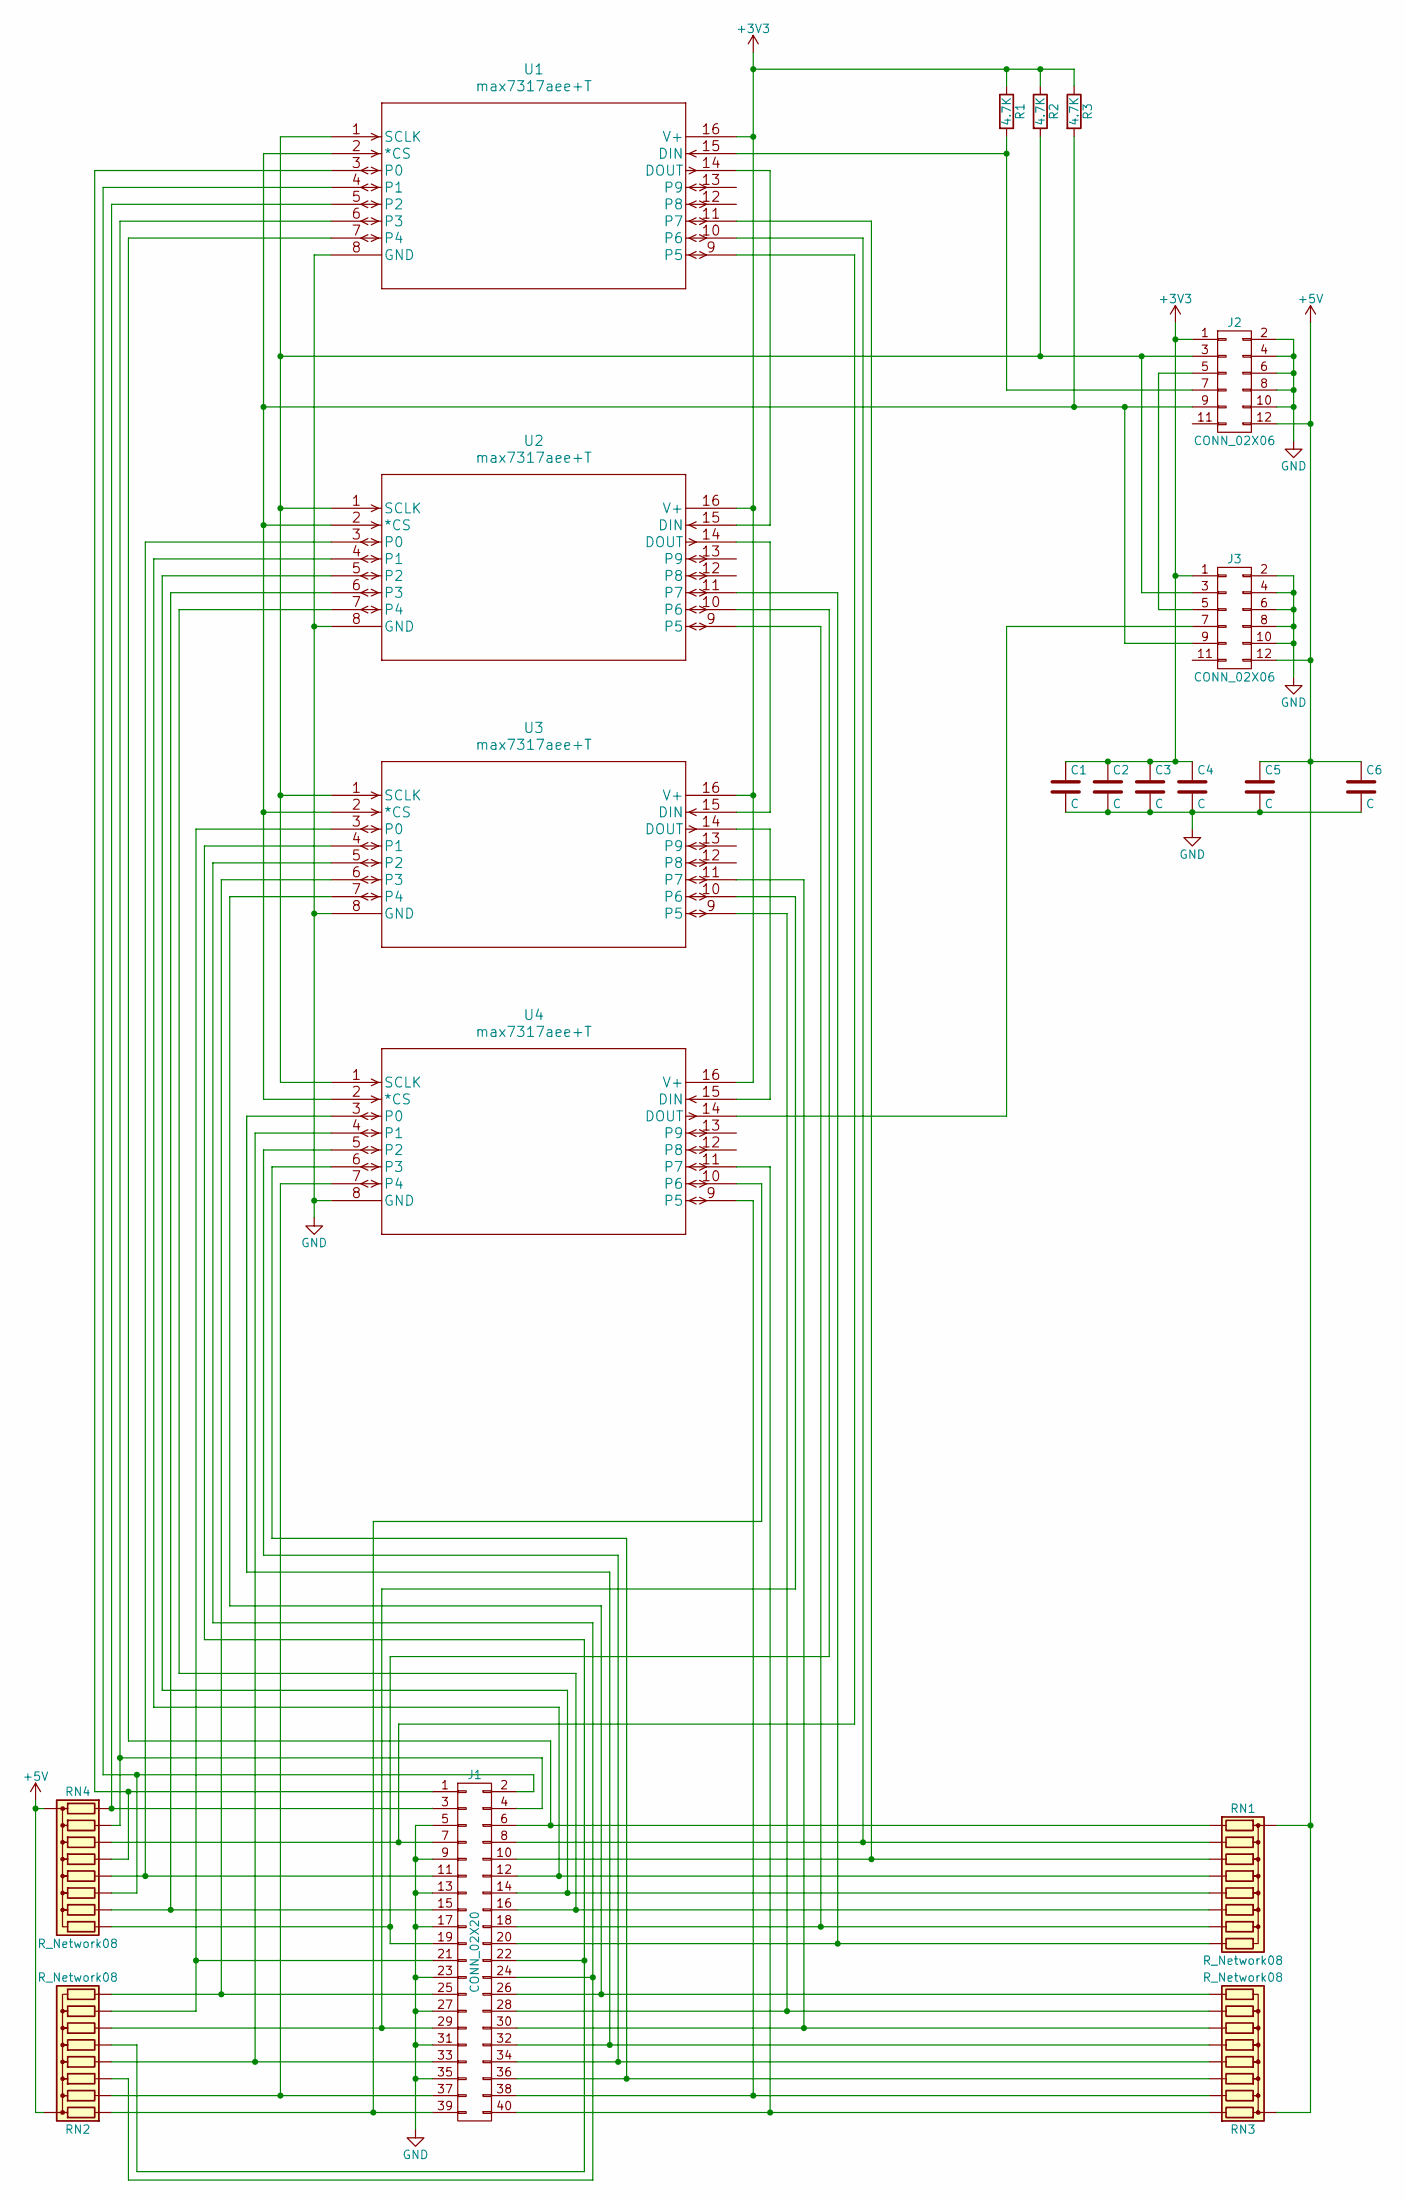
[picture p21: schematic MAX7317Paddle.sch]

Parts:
C1, C2, C3, C4: C; C_Rect_L7.0mm_W2.5mm_P5.00mm
C5, C6: C; C_Axial_L5.1mm_D3.1mm_P7.50mm_Horizontal
J1: CONN_02X20; Pin_Header_Straight_2x20_Pitch2.54mm
J2, J3: CONN_02X06; Pin_Header_Straight_2x06_Pitch2.54mm
R1, R2, R3: 4.7K; R_Axial_DIN0204_L3.6mm_D1.6mm_P5.08mm_Horizontal
RN1, RN2, RN3, RN4: R_Network08; R_Array_SIP9
U1, U2, U3, U4: max7317aee+T; max7317aee&plus_T

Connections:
+3V3: C1.1, C2.1, C3.1, C4.1, J2.1, J3.1, R1.1, R2.1, R3.1, U1.16 (V+), U2.16 (V+), U3.16 (V+), U4.16 (V+)
+5V: C5.1, C6.1, J2.12, J3.12, RN1.1 (common), RN2.1 (common), RN3.1 (common), RN4.1 (common)
GND: C1.2, C2.2, C3.2, C4.2, C5.2, C6.2, J1.5, J1.9, J1.13, J1.17, J1.23, J1.27, J1.31, J1.35, J2.2, J2.4, J2.6, J2.8, J2.10, J3.2, J3.4, J3.6, J3.8, J3.10, U1.8 (GND), U2.8 (GND), U3.8 (GND), U4.8 (GND)
unnamed: J1.1, RN4.5 (R4), U1.3 (P0)
unnamed: J1.2, RN4.7 (R6), U1.4 (P1)
unnamed: J1.3, RN4.2 (R1), U1.5 (P2)
unnamed: J1.4, RN4.3 (R2), U1.6 (P3)
unnamed: J1.6, RN1.2 (R1), U1.7 (P4)
unnamed: J1.7, RN4.4 (R3), U1.9 (P5)
unnamed: J1.8, RN1.3 (R2), U1.10 (P6)
unnamed: J1.10, RN1.4 (R3), U1.11 (P7)
unnamed: J1.11, RN4.6 (R5), U2.3 (P0)
unnamed: J1.12, RN1.5 (R4), U2.4 (P1)
unnamed: J1.14, RN1.6 (R5), U2.5 (P2)
unnamed: J1.15, RN4.8 (R7), U2.6 (P3)
unnamed: J1.16, RN1.7 (R6), U2.7 (P4)
unnamed: J1.18, RN1.8 (R7), U2.9 (P5)
unnamed: J1.19, RN4.9 (R8), U2.10 (P6)
unnamed: J1.20, RN1.9 (R8), U2.11 (P7)
unnamed: J1.21, RN2.8 (R7), U3.3 (P0)
unnamed: J1.22, RN2.6 (R5), U3.4 (P1)
unnamed: J1.24, RN2.4 (R3), U3.5 (P2)
unnamed: J1.25, RN2.9 (R8), U3.6 (P3)
unnamed: J1.26, RN3.9 (R8), U3.7 (P4)
unnamed: J1.28, RN3.8 (R7), U3.9 (P5)
unnamed: J1.29, RN2.7 (R6), U3.10 (P6)
unnamed: J1.30, RN3.7 (R6), U3.11 (P7)
unnamed: J1.32, RN3.6 (R5), U4.3 (P0)
unnamed: J1.33, RN2.5 (R4), U4.4 (P1)
unnamed: J1.34, RN3.5 (R4), U4.5 (P2)
unnamed: J1.36, RN3.4 (R3), U4.6 (P3)
unnamed: J1.37, RN2.3 (R2), U4.7 (P4)
unnamed: J1.38, RN3.3 (R2), U4.9 (P5)
unnamed: J1.39, RN2.2 (R1), U4.10 (P6)
unnamed: J1.40, RN3.2 (R1), U4.11 (P7)
unnamed: J2.3, J3.3, R2.2, U1.1 (SCLK), U2.1 (SCLK), U3.1 (SCLK), U4.1 (SCLK)
unnamed: J2.5, J3.5
unnamed: J2.7, R1.2, U1.15 (DIN)
unnamed: J2.9, J3.9, R3.2, U1.2 (*CS), U2.2 (*CS), U3.2 (*CS), U4.2 (*CS)
unnamed: J3.7, U4.14 (DOUT)
unnamed: U1.14 (DOUT), U2.15 (DIN)
unnamed: U2.14 (DOUT), U3.15 (DIN)
unnamed: U3.14 (DOUT), U4.15 (DIN)

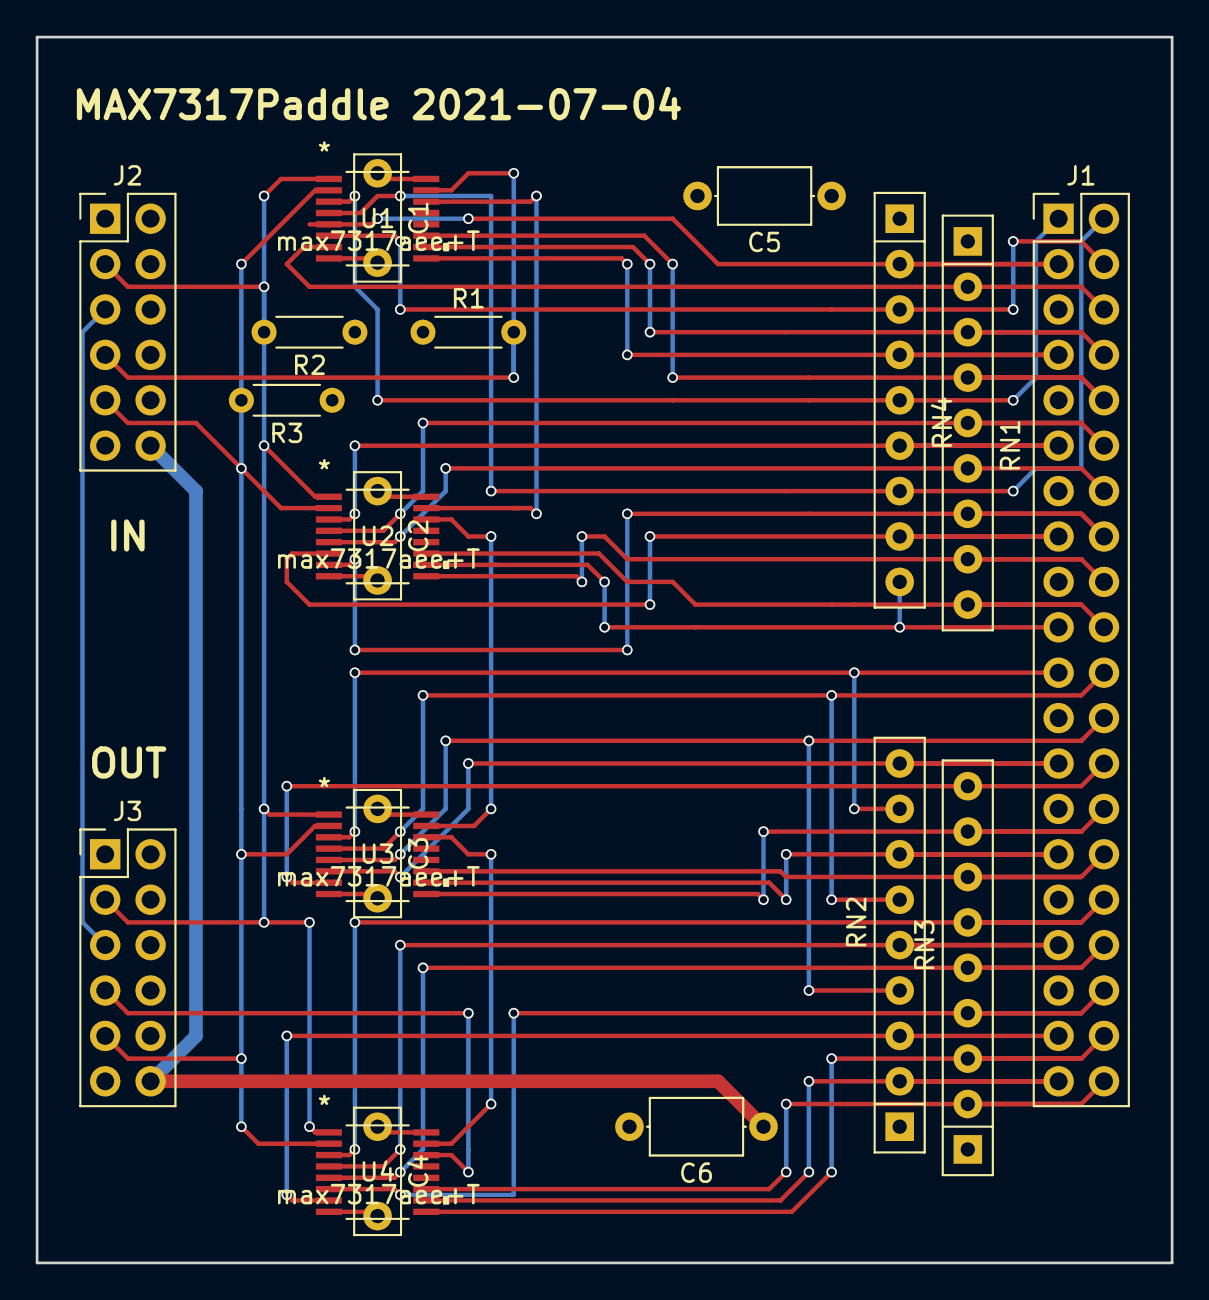
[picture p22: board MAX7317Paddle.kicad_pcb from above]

Board: 4 copper layers, 63.5 x 68.6 mm, 20 parts (0 on the bottom side), 43 nets.

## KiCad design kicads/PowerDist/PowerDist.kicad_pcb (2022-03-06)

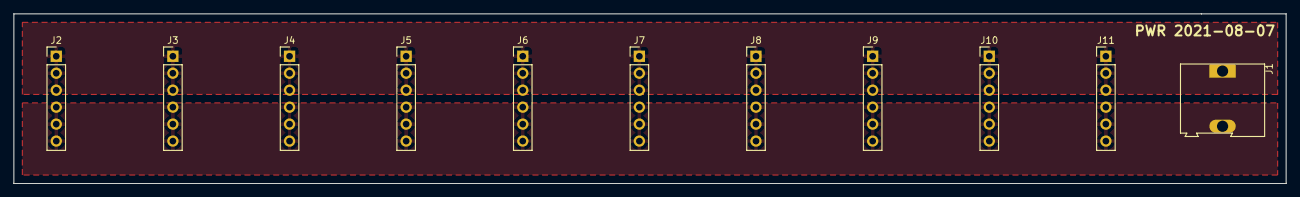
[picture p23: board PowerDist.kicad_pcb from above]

Board: 2 copper layers, 190.5 x 25.4 mm, 11 parts (0 on the bottom side), 2 nets, no tracks yet.

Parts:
J1: Screw_Terminal_1x02; AK300-2
J2, J3, J4, J5, J6, J7, J8, J9, J10, J11: CONN_01X06; Pin_Header_Straight_1x06_Pitch2.54mm

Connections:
GND: J1.2, J2.4, J2.5, J2.6, J3.4, J3.5, J3.6, J4.4, J4.5, J4.6, J5.4, J5.5, J5.6, J6.4, J6.5, J6.6, J7.4, J7.5, J7.6, J8.4, J8.5, J8.6, J9.4, J9.5, J9.6, J10.4, J10.5, J10.6, J11.4, J11.5, J11.6
VCC: J1.1, J2.1, J2.2, J2.3, J3.1, J3.2, J3.3, J4.1, J4.2, J4.3, J5.1, J5.2, J5.3, J6.1, J6.2, J6.3, J7.1, J7.2, J7.3, J8.1, J8.2, J8.3, J9.1, J9.2, J9.3, J10.1, J10.2, J10.3, J11.1, J11.2, J11.3

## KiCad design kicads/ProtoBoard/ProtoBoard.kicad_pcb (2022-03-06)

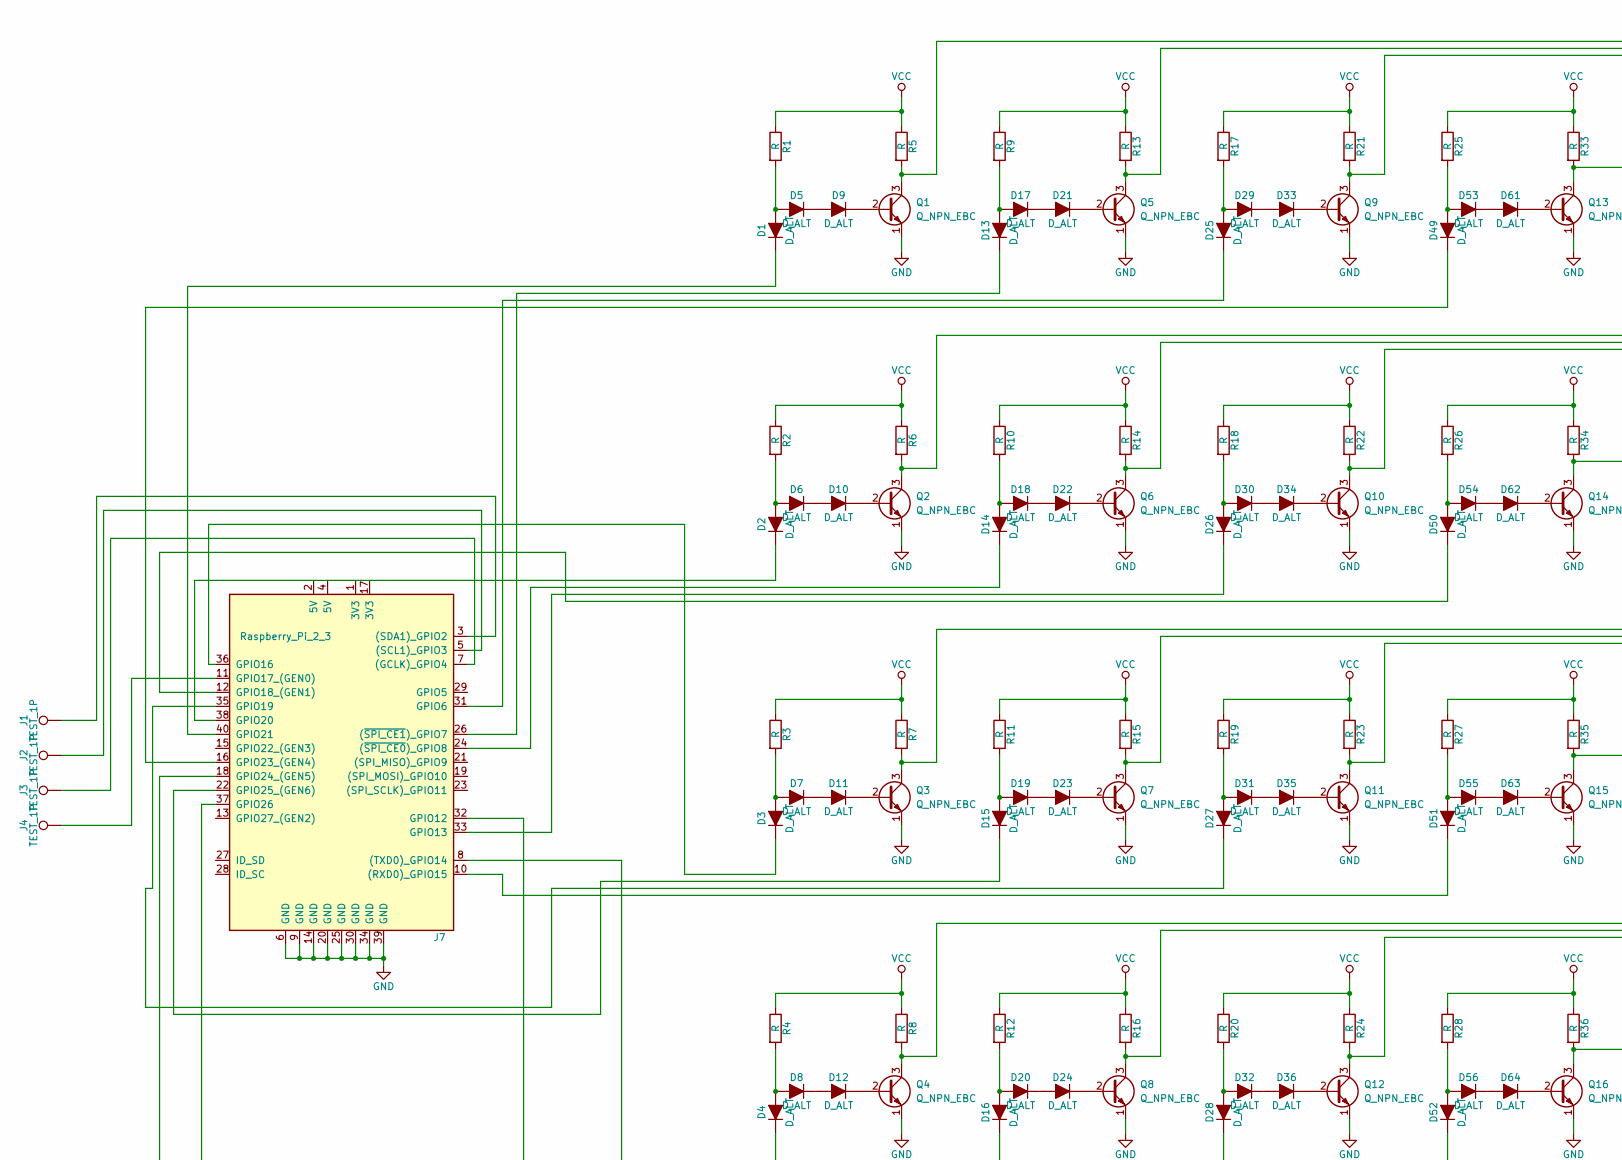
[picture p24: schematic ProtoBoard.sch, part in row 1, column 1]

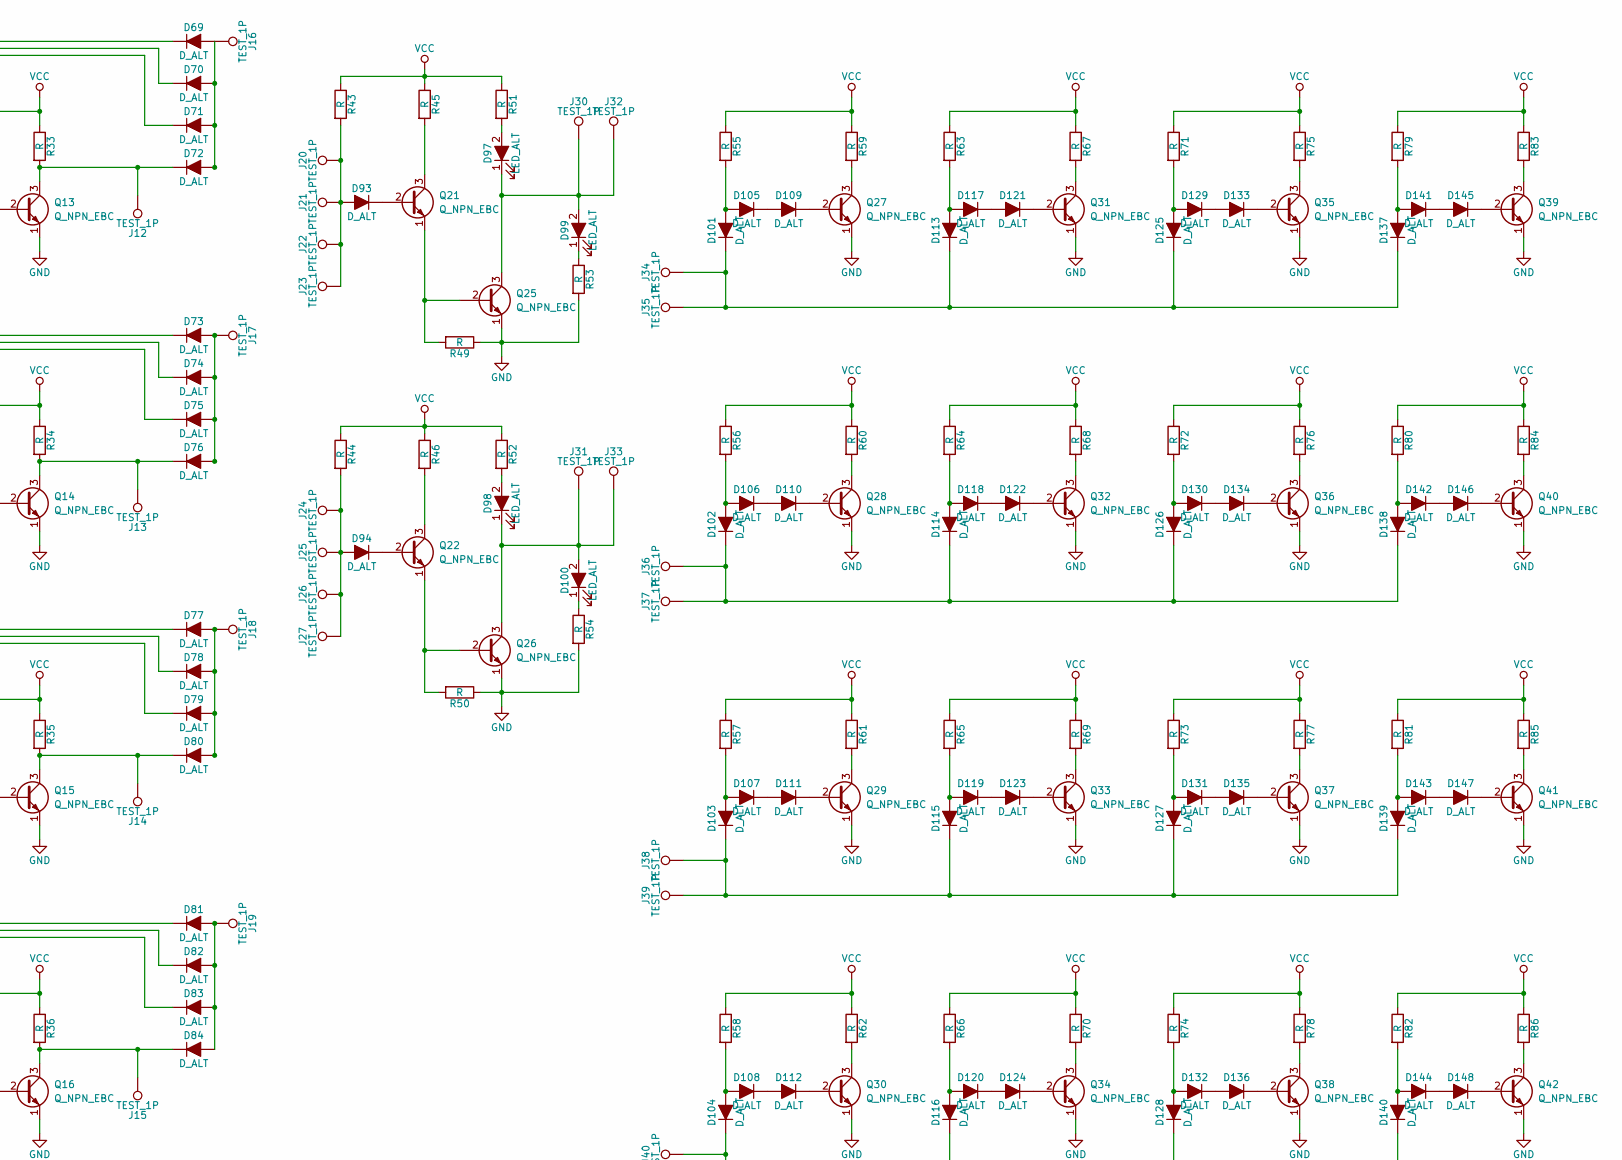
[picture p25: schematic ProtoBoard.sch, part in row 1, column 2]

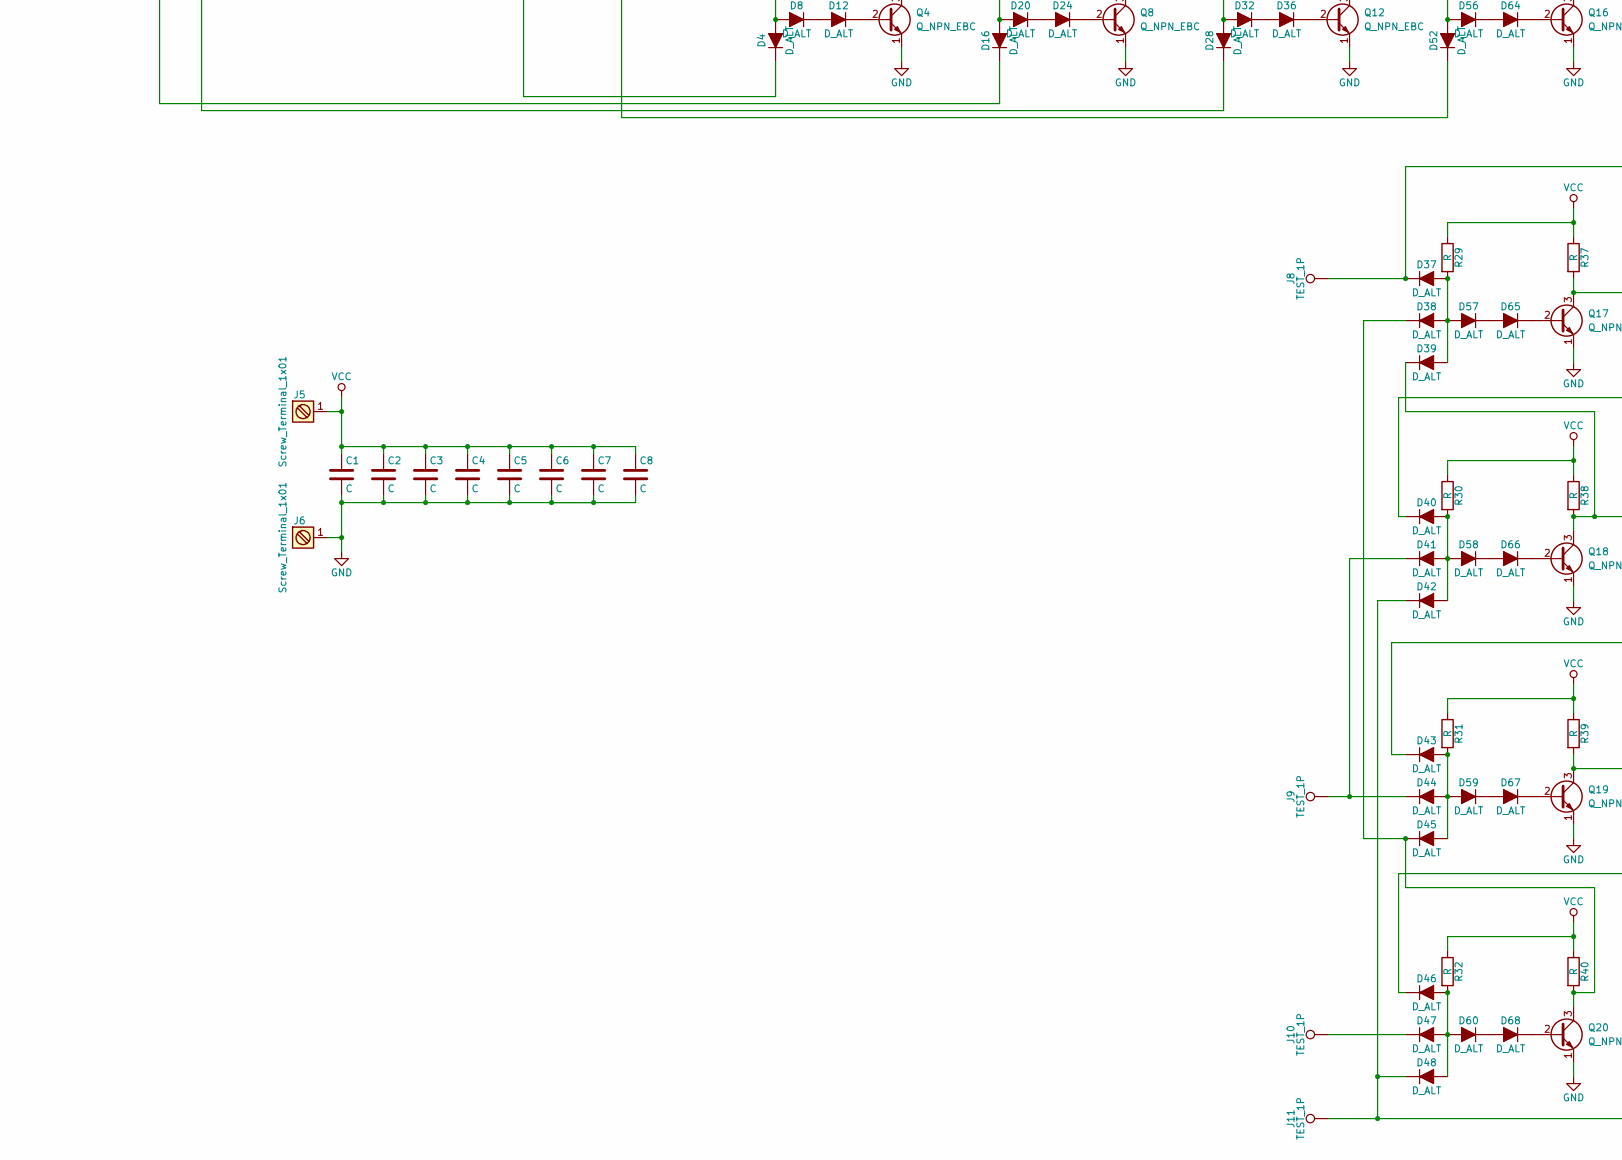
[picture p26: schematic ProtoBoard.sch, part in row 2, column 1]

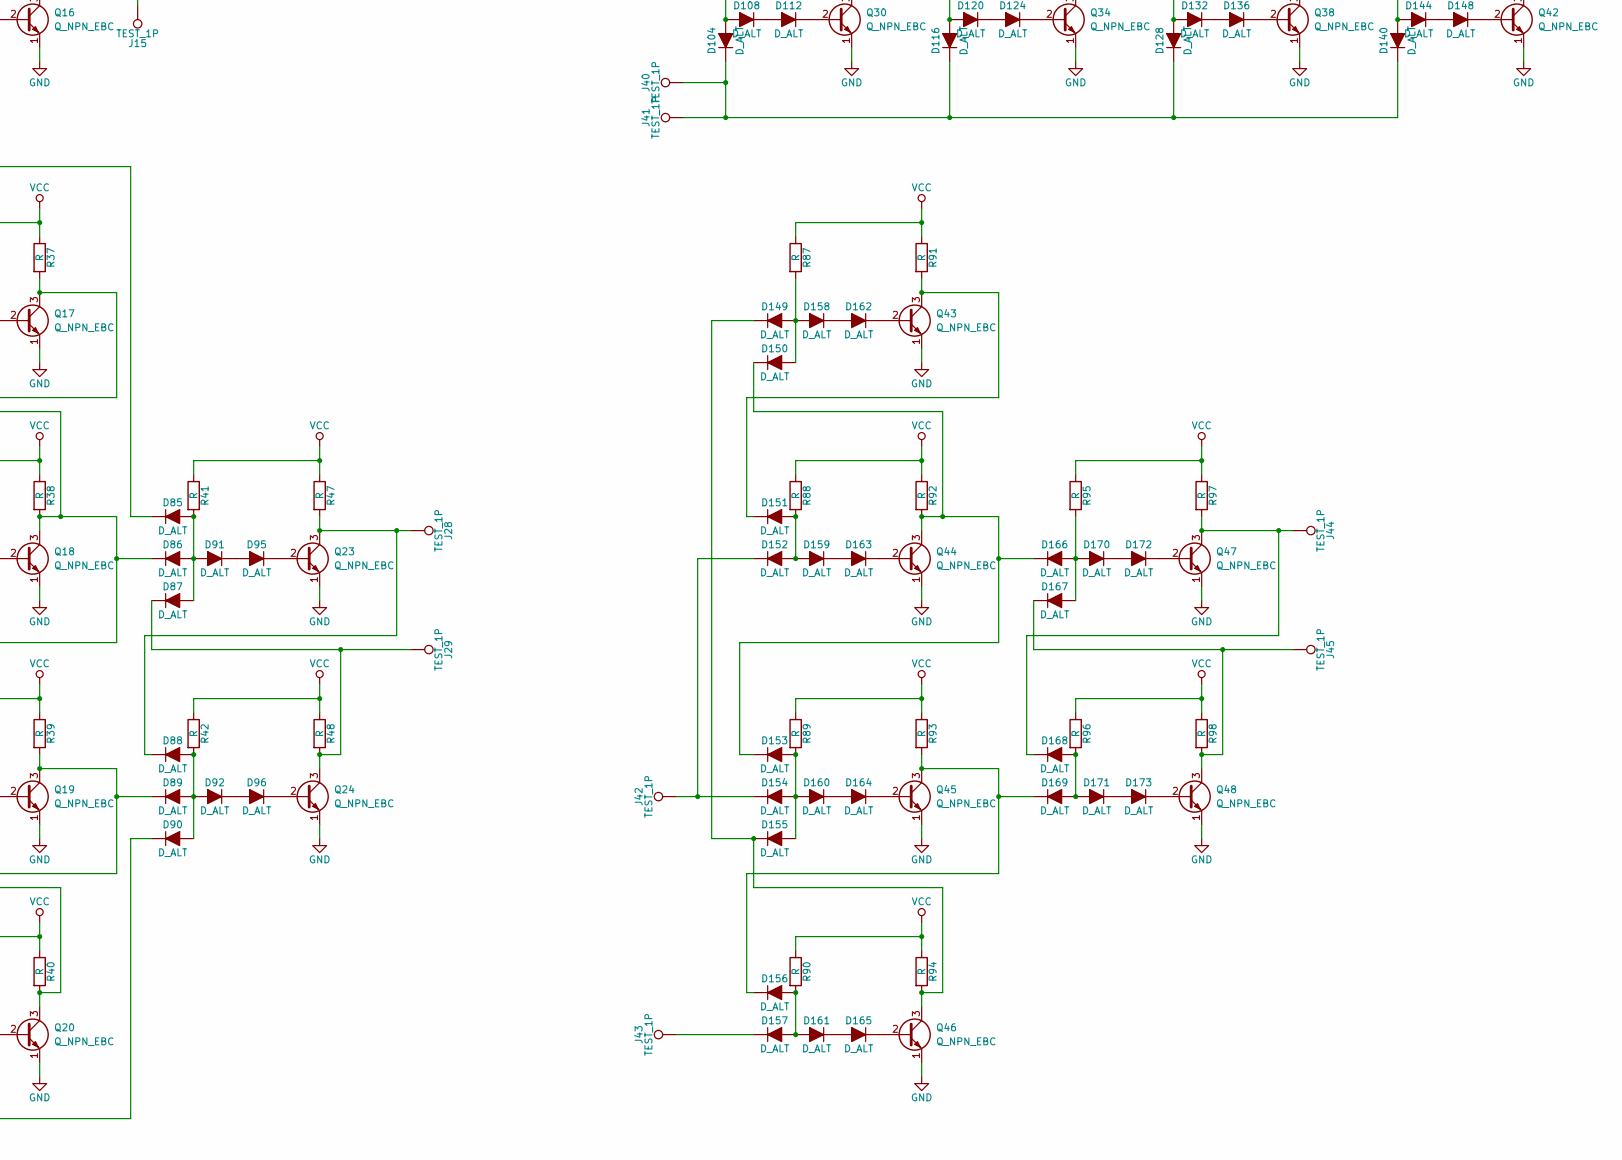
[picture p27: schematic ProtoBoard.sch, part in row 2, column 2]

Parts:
C1, C2, C3, C4, C5, C6, C7, C8: C; C_Axial_L12.0mm_D6.5mm_P15.00mm_Horizontal
D1, D2, D3, D4, D5, D6, D7, D8, D9, D10, D11, D12, D13, D14, D15, D16, D17, D18, D19, D20, D21, D22, D23, D24, D25, D26, D27, D28, D29, D30, D31, D32, D33, D34, D35, D36, D37, D38, D39, D40, D41, D42, D43, D44, D45, D46, D47, D48, D49, D50, D51, D52, D53, D54, D55, D56, D57, D58, D59, D60, D61, D62, D63, D64, D65, D66, D67, D68, D69, D70, D71, D72, D73, D74, D75, D76, D77, D78, D79, D80, D81, D82, D83, D84, D85, D86, D87, D88, D89, D90, D91, D92, D93, D94, D95, D96, D101, D102, D103, D104, D105, D106, D107, D108, D109, D110, D111, D112, D113, D114, D115, D116, D117, D118, D119, D120, D121, D122, D123, D124, D125, D126, D127, D128, D129, D130, D131, D132, D133, D134, D135, D136, D137, D138, D139, D140, D141, D142, D143, D144, D145, D146, D147, D148: D_ALT; D_DO-35_SOD27_P7.62mm_Horizontal
D97, D98, D99, D100: LED_ALT; LED_D3.0mm
D149, D150, D151, D152, D153, D154, D155, D156, D157, D158, D159, D160, D161, D162, D163, D164, D165, D166, D167, D168, D169, D170, D171, D172, D173: D_ALT; D_DO-35_SOD27_P2.54mm_Vertical_KathodeUp
J1, J2, J3, J4, J8, J9, J10, J11, J12, J13, J14, J15, J16, J17, J18, J19, J20, J21, J22, J23, J24, J25, J26, J27, J28, J29, J30, J31, J32, J33, J34, J35, J36, J37, J38, J39, J40, J41, J42, J43, J44, J45: TEST_1P; 1pin
J5, J6: Screw_Terminal_1x01; 1pin
J7: Raspberry_Pi_2_3; Multicomp_MC9A12-4034_2x20x2.54mm_Straight
Q1, Q2, Q3, Q4, Q5, Q6, Q7, Q8, Q9, Q10, Q11, Q12, Q13, Q14, Q15, Q16, Q17, Q18, Q19, Q20, Q21, Q22, Q23, Q24, Q25, Q26, Q27, Q28, Q29, Q30, Q31, Q32, Q33, Q34, Q35, Q36, Q37, Q38, Q39, Q40, Q41, Q42, Q43, Q44, Q45, Q46, Q47, Q48: Q_NPN_EBC; TO-92_Molded_Wide
R1, R2, R3, R4, R5, R6, R7, R8, R9, R10, R11, R12, R13, R14, R15, R16, R17, R18, R19, R20, R21, R22, R23, R24, R25, R26, R27, R28, R29, R30, R31, R32, R33, R34, R35, R36, R37, R38, R39, R40, R41, R42, R43, R44, R45, R46, R47, R48, R49, R50, R51, R52, R53, R54, R55, R56, R57, R58, R59, R60, R61, R62, R63, R64, R65, R66, R67, R68, R69, R70, R71, R72, R73, R74, R75, R76, R77, R78, R79, R80, R81, R82, R83, R84, R85, R86: R; R_Axial_DIN0207_L6.3mm_D2.5mm_P10.16mm_Horizontal
R87, R88, R89, R90, R91, R92, R93, R94, R95, R96, R97, R98: R; R_Axial_DIN0207_L6.3mm_D2.5mm_P2.54mm_Vertical

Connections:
GND: C1.2, C2.2, C3.2, C4.2, C5.2, C6.2, C7.2, C8.2, J6.1, J7.6 (GND), J7.9 (GND), J7.14 (GND), J7.20 (GND), J7.25 (GND), J7.30 (GND), J7.34 (GND), J7.39 (GND), Q1.1 (E), Q2.1 (E), Q3.1 (E), Q4.1 (E), Q5.1 (E), Q6.1 (E), Q7.1 (E), Q8.1 (E), Q9.1 (E), Q10.1 (E), Q11.1 (E), Q12.1 (E), Q13.1 (E), Q14.1 (E), Q15.1 (E), Q16.1 (E), Q17.1 (E), Q18.1 (E), Q19.1 (E), Q20.1 (E), Q23.1 (E), Q24.1 (E), Q25.1 (E), Q26.1 (E), Q27.1 (E), Q28.1 (E), Q29.1 (E), Q30.1 (E), Q31.1 (E), Q32.1 (E), Q33.1 (E), Q34.1 (E), Q35.1 (E), Q36.1 (E), Q37.1 (E), Q38.1 (E), Q39.1 (E), Q40.1 (E), Q41.1 (E), Q42.1 (E), Q43.1 (E), Q44.1 (E), Q45.1 (E), Q46.1 (E), Q47.1 (E), Q48.1 (E), R49.1, R50.1, R53.2, R54.2
unnamed: D1.1 (K), J7.40 (GPIO21)
unnamed: D1.2 (A), D5.2 (A), R1.2
unnamed: D2.1 (K), J7.38 (GPIO20)
unnamed: D2.2 (A), D6.2 (A), R2.2
unnamed: D3.1 (K), J7.36 (GPIO16)
unnamed: D3.2 (A), D7.2 (A), R3.2
unnamed: D4.1 (K), J7.32 (GPIO12)
unnamed: D4.2 (A), D8.2 (A), R4.2
unnamed: D5.1 (K), D9.2 (A)
unnamed: D9.1 (K), Q1.2 (B)
unnamed: D10.1 (K), Q2.2 (B)
unnamed: D6.1 (K), D10.2 (A)
unnamed: D11.1 (K), Q3.2 (B)
unnamed: D7.1 (K), D11.2 (A)
unnamed: D12.1 (K), Q4.2 (B)
unnamed: D8.1 (K), D12.2 (A)
unnamed: D13.1 (K), J7.26 ((~SPI_CE1~)_GPIO7)
unnamed: D13.2 (A), D17.2 (A), R9.2
unnamed: D14.1 (K), J7.24 ((~SPI_CE0~)_GPIO8)
unnamed: D14.2 (A), D18.2 (A), R10.2
unnamed: D15.1 (K), J7.22 (GPIO25_(GEN6))
unnamed: D15.2 (A), D19.2 (A), R11.2
unnamed: D16.1 (K), J7.18 (GPIO24_(GEN5))
unnamed: D16.2 (A), D20.2 (A), R12.2
unnamed: D17.1 (K), D21.2 (A)
unnamed: D18.1 (K), D22.2 (A)
unnamed: D19.1 (K), D23.2 (A)
unnamed: D20.1 (K), D24.2 (A)
unnamed: D21.1 (K), Q5.2 (B)
unnamed: D22.1 (K), Q6.2 (B)
unnamed: D23.1 (K), Q7.2 (B)
unnamed: D24.1 (K), Q8.2 (B)
unnamed: D25.1 (K), J7.31 (GPIO6)
unnamed: D25.2 (A), D29.2 (A), R17.2
unnamed: D26.1 (K), J7.33 (GPIO13)
unnamed: D26.2 (A), D30.2 (A), R18.2
unnamed: D27.1 (K), J7.35 (GPIO19)
unnamed: D27.2 (A), D31.2 (A), R19.2
unnamed: D28.1 (K), J7.37 (GPIO26)
unnamed: D28.2 (A), D32.2 (A), R20.2
unnamed: D29.1 (K), D33.2 (A)
unnamed: D30.1 (K), D34.2 (A)
unnamed: D31.1 (K), D35.2 (A)
unnamed: D32.1 (K), D36.2 (A)
unnamed: D33.1 (K), Q9.2 (B)
unnamed: D34.1 (K), Q10.2 (B)
unnamed: D35.1 (K), Q11.2 (B)
unnamed: D36.1 (K), Q12.2 (B)
unnamed: D37.1 (K), D85.1 (K), J8.1
unnamed: D37.2 (A), D38.2 (A), D39.2 (A), D57.2 (A), R29.2
unnamed: D38.1 (K), D45.1 (K), Q20.3 (C), R40.2
unnamed: D39.1 (K), D43.1 (K), D86.1 (K), Q18.3 (C), R38.2
unnamed: D40.1 (K), Q17.3 (C), R37.2
unnamed: D40.2 (A), D41.2 (A), D42.2 (A), D58.2 (A), R30.2
unnamed: D41.1 (K), D44.1 (K), J9.1
unnamed: D42.1 (K), D48.1 (K), D90.1 (K), J11.1
unnamed: D43.2 (A), D44.2 (A), D45.2 (A), D59.2 (A), R31.2
unnamed: D46.1 (K), D89.1 (K), Q19.3 (C), R39.2
unnamed: D46.2 (A), D47.2 (A), D48.2 (A), D60.2 (A), R32.2
unnamed: D47.1 (K), J10.1
unnamed: D49.1 (K), J7.16 (GPIO23_(GEN4))
unnamed: D49.2 (A), D53.2 (A), R25.2
unnamed: D50.1 (K), J7.12 (GPIO18_(GEN1))
unnamed: D50.2 (A), D54.2 (A), R26.2
unnamed: D51.1 (K), J7.10 ((RXD0)_GPIO15)
unnamed: D51.2 (A), D55.2 (A), R27.2
unnamed: D52.1 (K), J7.8 ((TXD0)_GPIO14)
unnamed: D52.2 (A), D56.2 (A), R28.2
unnamed: D53.1 (K), D61.2 (A)
unnamed: D54.1 (K), D62.2 (A)
unnamed: D55.1 (K), D63.2 (A)
unnamed: D56.1 (K), D64.2 (A)
unnamed: D57.1 (K), D65.2 (A)
unnamed: D58.1 (K), D66.2 (A)
unnamed: D59.1 (K), D67.2 (A)
unnamed: D60.1 (K), D68.2 (A)
unnamed: D61.1 (K), Q13.2 (B)
unnamed: D62.1 (K), Q14.2 (B)
unnamed: D63.1 (K), Q15.2 (B)
unnamed: D64.1 (K), Q16.2 (B)
unnamed: D65.1 (K), Q17.2 (B)
unnamed: D66.1 (K), Q18.2 (B)
unnamed: D67.1 (K), Q19.2 (B)
unnamed: D68.1 (K), Q20.2 (B)
unnamed: D69.1 (K), Q1.3 (C), R5.2
unnamed: D69.2 (A), D70.2 (A), D71.2 (A), D72.2 (A), J16.1
unnamed: D70.1 (K), Q5.3 (C), R13.2
unnamed: D71.1 (K), Q9.3 (C), R21.2
unnamed: D72.1 (K), J12.1, Q13.3 (C), R33.2
unnamed: D73.1 (K), Q2.3 (C), R6.2
unnamed: D73.2 (A), D74.2 (A), D75.2 (A), D76.2 (A), J17.1
unnamed: D74.1 (K), Q6.3 (C), R14.2
unnamed: D75.1 (K), Q10.3 (C), R22.2
unnamed: D76.1 (K), J13.1, Q14.3 (C), R34.2
unnamed: D77.1 (K), Q3.3 (C), R7.2
unnamed: D77.2 (A), D78.2 (A), D79.2 (A), D80.2 (A), J18.1
unnamed: D78.1 (K), Q7.3 (C), R15.2
unnamed: D79.1 (K), Q11.3 (C), R23.2
unnamed: D80.1 (K), J14.1, Q15.3 (C), R35.2
unnamed: D81.1 (K), Q4.3 (C), R8.2
unnamed: D81.2 (A), D82.2 (A), D83.2 (A), D84.2 (A), J19.1
unnamed: D82.1 (K), Q8.3 (C), R16.2
unnamed: D83.1 (K), Q12.3 (C), R24.2
unnamed: D84.1 (K), J15.1, Q16.3 (C), R36.2
unnamed: D85.2 (A), D86.2 (A), D87.2 (A), D91.2 (A), R41.2
unnamed: D87.1 (K), J29.1, Q24.3 (C), R48.2
unnamed: D88.1 (K), J28.1, Q23.3 (C), R47.2
unnamed: D88.2 (A), D89.2 (A), D90.2 (A), D92.2 (A), R42.2
unnamed: D91.1 (K), D95.2 (A)
unnamed: D92.1 (K), D96.2 (A)
unnamed: D93.1 (K), Q21.2 (B)
unnamed: D93.2 (A), J20.1, J21.1, J22.1, J23.1, R43.2
unnamed: D94.1 (K), Q22.2 (B)
unnamed: D94.2 (A), J24.1, J25.1, J26.1, J27.1, R44.2
unnamed: D95.1 (K), Q23.2 (B)
unnamed: D96.1 (K), Q24.2 (B)
unnamed: D97.1 (K), D99.2 (A), J30.1, J32.1, Q25.3 (C)
unnamed: D97.2 (A), R51.2
unnamed: D98.2 (A), R52.2
unnamed: D99.1 (K), R53.1
unnamed: D100.1 (K), R54.1
unnamed: D98.1 (K), D100.2 (A), J31.1, J33.1, Q26.3 (C)
unnamed: D101.1 (K), D113.1 (K), D125.1 (K), D137.1 (K), J34.1, J35.1
unnamed: D101.2 (A), D105.2 (A), R55.2
unnamed: D102.1 (K), D114.1 (K), D126.1 (K), D138.1 (K), J36.1, J37.1
unnamed: D102.2 (A), D106.2 (A), R56.2
unnamed: D103.1 (K), D115.1 (K), D127.1 (K), D139.1 (K), J38.1, J39.1
unnamed: D103.2 (A), D107.2 (A), R57.2
unnamed: D104.1 (K), D116.1 (K), D128.1 (K), D140.1 (K), J40.1, J41.1
unnamed: D104.2 (A), D108.2 (A), R58.2
unnamed: D105.1 (K), D109.2 (A)
unnamed: D106.1 (K), D110.2 (A)
unnamed: D107.1 (K), D111.2 (A)
unnamed: D108.1 (K), D112.2 (A)
unnamed: D109.1 (K), Q27.2 (B)
unnamed: D110.1 (K), Q28.2 (B)
unnamed: D111.1 (K), Q29.2 (B)
unnamed: D112.1 (K), Q30.2 (B)
unnamed: D113.2 (A), D117.2 (A), R63.2
unnamed: D114.2 (A), D118.2 (A), R64.2
unnamed: D115.2 (A), D119.2 (A), R65.2
unnamed: D116.2 (A), D120.2 (A), R66.2
unnamed: D117.1 (K), D121.2 (A)
unnamed: D118.1 (K), D122.2 (A)
unnamed: D119.1 (K), D123.2 (A)
unnamed: D120.1 (K), D124.2 (A)
unnamed: D121.1 (K), Q31.2 (B)
unnamed: D122.1 (K), Q32.2 (B)
unnamed: D123.1 (K), Q33.2 (B)
unnamed: D124.1 (K), Q34.2 (B)
unnamed: D125.2 (A), D129.2 (A), R71.2
unnamed: D126.2 (A), D130.2 (A), R72.2
unnamed: D127.2 (A), D131.2 (A), R73.2
unnamed: D128.2 (A), D132.2 (A), R74.2
unnamed: D129.1 (K), D133.2 (A)
unnamed: D130.1 (K), D134.2 (A)
unnamed: D131.1 (K), D135.2 (A)
unnamed: D132.1 (K), D136.2 (A)
unnamed: D133.1 (K), Q35.2 (B)
unnamed: D134.1 (K), Q36.2 (B)
unnamed: D135.1 (K), Q37.2 (B)
unnamed: D136.1 (K), Q38.2 (B)
unnamed: D137.2 (A), D141.2 (A), R79.2
unnamed: D138.2 (A), D142.2 (A), R80.2
unnamed: D139.2 (A), D143.2 (A), R81.2
unnamed: D140.2 (A), D144.2 (A), R82.2
unnamed: D141.1 (K), D145.2 (A)
unnamed: D142.1 (K), D146.2 (A)
unnamed: D143.1 (K), D147.2 (A)
unnamed: D144.1 (K), D148.2 (A)
unnamed: D145.1 (K), Q39.2 (B)
unnamed: D146.1 (K), Q40.2 (B)
unnamed: D147.1 (K), Q41.2 (B)
unnamed: D148.1 (K), Q42.2 (B)
unnamed: D149.1 (K), D155.1 (K), Q46.3 (C), R94.2
unnamed: D149.2 (A), D150.2 (A), D158.2 (A), R87.2
unnamed: D150.1 (K), D153.1 (K), D166.1 (K), Q44.3 (C), R92.2
unnamed: D151.1 (K), Q43.3 (C), R91.2
unnamed: D151.2 (A), D152.2 (A), D159.2 (A), R88.2
unnamed: D152.1 (K), D154.1 (K), J42.1
unnamed: D153.2 (A), D154.2 (A), D155.2 (A), D160.2 (A), R89.2
unnamed: D156.1 (K), D169.1 (K), Q45.3 (C), R93.2
unnamed: D156.2 (A), D157.2 (A), D161.2 (A), R90.2
unnamed: D157.1 (K), J43.1
unnamed: D158.1 (K), D162.2 (A)
unnamed: D159.1 (K), D163.2 (A)
unnamed: D160.1 (K), D164.2 (A)
unnamed: D161.1 (K), D165.2 (A)
unnamed: D162.1 (K), Q43.2 (B)
unnamed: D163.1 (K), Q44.2 (B)
unnamed: D164.1 (K), Q45.2 (B)
unnamed: D165.1 (K), Q46.2 (B)
unnamed: D166.2 (A), D167.2 (A), D170.2 (A), R95.2
unnamed: D167.1 (K), J45.1, Q48.3 (C), R98.2
unnamed: D168.1 (K), J44.1, Q47.3 (C), R97.2
unnamed: D168.2 (A), D169.2 (A), D171.2 (A), R96.2
unnamed: D170.1 (K), D172.2 (A)
unnamed: D171.1 (K), D173.2 (A)
unnamed: D172.1 (K), Q47.2 (B)
unnamed: D173.1 (K), Q48.2 (B)
unnamed: J1.1, J7.3 ((SDA1)_GPIO2)
unnamed: J2.1, J7.5 ((SCL1)_GPIO3)
unnamed: J3.1, J7.7 ((GCLK)_GPIO4)
unnamed: J4.1, J7.11 (GPIO17_(GEN0))
unnamed: Q21.1 (E), Q25.2 (B), R49.2
unnamed: Q21.3 (C), R45.2
unnamed: Q22.1 (E), Q26.2 (B), R50.2
unnamed: Q22.3 (C), R46.2
unnamed: Q27.3 (C), R59.2
unnamed: Q28.3 (C), R60.2
unnamed: Q29.3 (C), R61.2
unnamed: Q30.3 (C), R62.2
unnamed: Q31.3 (C), R67.2
unnamed: Q32.3 (C), R68.2
unnamed: Q33.3 (C), R69.2
unnamed: Q34.3 (C), R70.2
unnamed: Q35.3 (C), R75.2
unnamed: Q36.3 (C), R76.2
unnamed: Q37.3 (C), R77.2
unnamed: Q38.3 (C), R78.2
unnamed: Q39.3 (C), R83.2
unnamed: Q40.3 (C), R84.2
unnamed: Q41.3 (C), R85.2
unnamed: Q42.3 (C), R86.2
VCC: C1.1, C2.1, C3.1, C4.1, C5.1, C6.1, C7.1, C8.1, J5.1, R1.1, R2.1, R3.1, R4.1, R5.1, R6.1, R7.1, R8.1, R9.1, R10.1, R11.1, R12.1, R13.1, R14.1, R15.1, R16.1, R17.1, R18.1, R19.1, R20.1, R21.1, R22.1, R23.1, R24.1, R25.1, R26.1, R27.1, R28.1, R29.1, R30.1, R31.1, R32.1, R33.1, R34.1, R35.1, R36.1, R37.1, R38.1, R39.1, R40.1, R41.1, R42.1, R43.1, R44.1, R45.1, R46.1, R47.1, R48.1, R51.1, R52.1, R55.1, R56.1, R57.1, R58.1, R59.1, R60.1, R61.1, R62.1, R63.1, R64.1, R65.1, R66.1, R67.1, R68.1, R69.1, R70.1, R71.1, R72.1, R73.1, R74.1, R75.1, R76.1, R77.1, R78.1, R79.1, R80.1, R81.1, R82.1, R83.1, R84.1, R85.1, R86.1, R87.1, R88.1, R89.1, R90.1, R91.1, R92.1, R93.1, R94.1, R95.1, R96.1, R97.1, R98.1

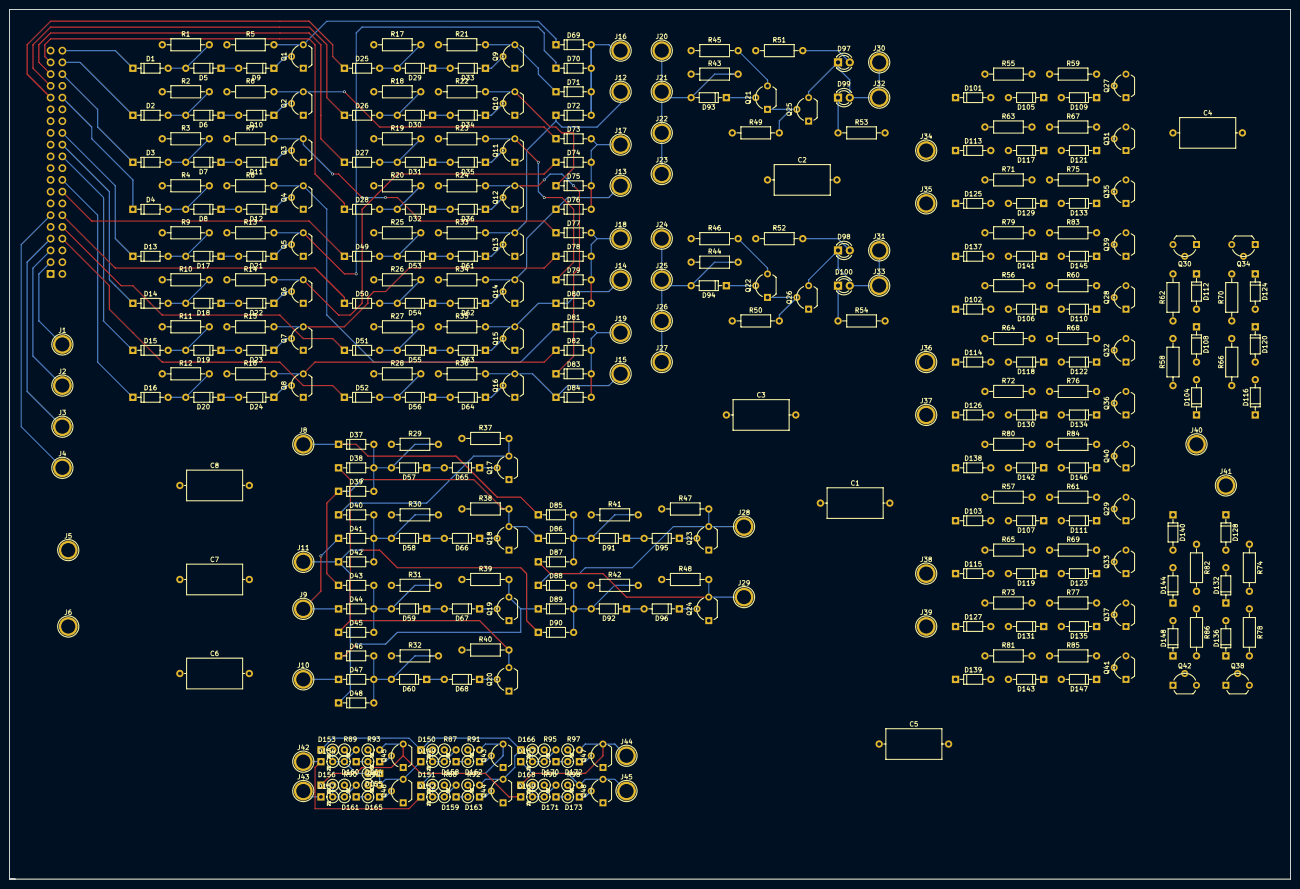
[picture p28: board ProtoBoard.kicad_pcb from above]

Board: 4 copper layers, 276.9 x 188.0 mm, 372 parts (1 on the bottom side), 226 nets.

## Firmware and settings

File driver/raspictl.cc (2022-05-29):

//    Copyright (C) Mike Rieker, Beverly, MA USA
//    www.outerworldapps.com
//
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
//    EXPECT it to FAIL when someone's HeALTh or PROpeRTy is at RISk.
//
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
//    http://www.gnu.org/licenses/gpl-2.0.html

/**
 * Program runs on the raspberry pi to control the computer.
 *
 *  ../asm/assemble.armv7l r6loop.asm r6loop.hex [cmdargs ...] > r6loop.lis
 *  . ./iow56sns.si
 *  sudo -E gdb --args ./raspictl [-chkacid] [-cpuhz <freq>] [-haltstop] [-mintimes] [-nohw] [-oddok] [-printstate] [-sim <pipename>] -randmem | r6loop.hex
 *      -chkacid    : check A,C,I,D connectors at end of each cycle (requires paddles)
 *      -cpuhz      : specify cpu frequency (default 470000Hz)
 *      -haltstop   : HALT instruction causes exit (else it is 'wait for interrupt')
 *      -mintimes   : print cpu cycle info once a minute
 *      -nohw       : don't use hardware, simulate processor internally
 *      -oddok      : odd addresses ok (swaps bytes) (else give warning message)
 *      -printinstr : print message at beginning of each instruction
 *      -printstate : print message at beginning of each state
 *      -randmem    : supply random opcodes and data for testing
 *      -sim        : simulate via pipe connected to NetGen
 *      -stopat     : stop simulating when accessing the address
 *      -tclhex     : tcl assembler generated hex file format
 */

#include <errno.h>
#include <fcntl.h>
#include <map>
#include <math.h>
#include <pthread.h>
#include <sched.h>
#include <signal.h>
#include <stdio.h>
#include <stdlib.h>
#include <string.h>
#include <sys/mman.h>
#include <sys/time.h>
#include <termios.h>
#include <time.h>
#include <unistd.h>

#include "gpiolib.h"
#include "miscdefs.h"
#include "rdcyc.h"
#include "shadow.h"

#define SHADOWCHECK(samp) shadowcheck (samp)

#define MAGIC 0xFFF0
#define ERRNO 0xFFF2

#define SCN_EXIT 0
#define SCN_PRINTLN 1
#define SCN_INTREQ 2
#define SCN_CLOSE 3
#define SCN_GETNOWNS 4
#define SCN_OPEN 5
#define SCN_READ 6
#define SCN_WRITE 7
#define SCN_IRQATNS 8
#define SCN_INTACK 9
#define SCN_UNLINK 10
#define SCN_GETCMDARG 11
#define SCN_ADD_DDD 12
#define SCN_ADD_FFF 13
#define SCN_SUB_DDD 14
#define SCN_SUB_FFF 15
#define SCN_MUL_DDD 16
#define SCN_MUL_FFF 17
#define SCN_DIV_DDD 18
#define SCN_DIV_FFF 19
#define SCN_CMP_DD 20
#define SCN_CMP_FF 21
#define SCN_CVT_FP 22
#define SCN_UDIV 23
#define SCN_UMUL 24
#define SCN_SETROSIZE 25
#define SCN_SETSTKLIM 26
#define SCN_PRINTINSTR 27
#define SCN_NEG_DD 28
#define SCN_NEG_FF 29
#define SCN_WATCHWRITE 30
#define SCN_GETENV 31
#define SCN_SETTTYECHO 32

#define IRQ_SCNINTREQ 0x1
#define IRQ_LINECLOCK 0x2
#define IRQ_RANDMEM   0x4

#define ever (;;)

typedef uint16_t MagicReader (uint32_t sample);
typedef void MagicWriter (uint32_t sample, uint16_t data);

static bool lineclockrun;
static char **cmdargv;
static GpioLib *gpio;
static int cmdargc;
static pthread_cond_t intreqcond = PTHREAD_COND_INITIALIZER;
static pthread_cond_t lineclockcond = PTHREAD_COND_INITIALIZER;
static pthread_mutex_t intreqlock = PTHREAD_MUTEX_INITIALIZER;
static Shadow shadow;
static std::map<int,struct termios> savedtermioss;
static struct timespec lineclockabs;
static uint16_t readonlysize;
static uint16_t stacklimit;
static uint32_t intreqreg;
static uint32_t syncintreq;
static uint32_t watchwrite;
static uint8_t memory[0x10000];
static uint32_t readcounts[0x8000];

static uint16_t mr_syscall (uint32_t sample);
static void mw_syscall (uint32_t sample, uint16_t data);

static MagicReader *const magicreaders[] = { mr_syscall };
static MagicWriter *const magicwriters[] = { mw_syscall };

static void save_errno ();
static void *mintimesthread (void *dummy);
static void *lineclockthread (void *dummy);
static int twohexchars (char const *str);
static uint16_t randopcode ();
static uint16_t randuint16 ();
static void dumpregs ();
static void senddata (uint16_t data);
static uint16_t recvdata (void);
static uint16_t readmemword (uint32_t addr);
static uint32_t readmemlong (uint32_t addr);
static uint64_t readmemquad (uint32_t addr);
static double   readmemdoub (uint32_t addr);
static float    readmemflt  (uint32_t addr);
static void writememlong (uint32_t addr, uint32_t val);
static void writememquad (uint32_t addr, uint64_t val);
static void writememdoub (uint32_t addr, double   val);
static void writememflt  (uint32_t addr, float    val);
static void *getmemptr (uint32_t addr, uint32_t size, bool write);
static char const *getmemstr (uint32_t addr);
static void shadowcheck (uint32_t sample);
static void sighandler (int signum);
static void exithandler ();

int main (int argc, char **argv)
{
    bool haltstop = false;
    bool mintimes = false;
    bool nohw = false;
    bool oddok = false;
    bool randmem = false;
    bool tclhex = false;
    char const *loadname = NULL;
    char const *simname = NULL;
    char *p;
    int randinit = 0;
    uint16_t lastmemread = 0;
    uint32_t cpuhz = DEFCPUHZ;
    uint32_t stopataddr = -1;

    setlinebuf (stdout);

    for (int i = 0; ++ i < argc;) {
        if (strcasecmp (argv[i], "-chkacid") == 0) {
            shadow.chkacid = true;
            continue;
        }
        if (strcasecmp (argv[i], "-cpuhz") == 0) {
            if ((++ i >= argc) || (argv[i][0] == '-')) {
                fprintf (stderr, "raspictl: missing freq after -cpuhz\n");
                return 1;
            }
            cpuhz = atoi (argv[i]);
            continue;
        }
        if (strcasecmp (argv[i], "-haltstop") == 0) {
            haltstop = true;
            continue;
        }
        if (strcasecmp (argv[i], "-mintimes") == 0) {
            mintimes = true;
            continue;
        }
        if (strcasecmp (argv[i], "-nohw") == 0) {
            nohw = true;
            continue;
        }
        if (strcasecmp (argv[i], "-oddok") == 0) {
            oddok = true;
            continue;
        }
        if (strcasecmp (argv[i], "-printinstr") == 0) {
            shadow.printinstr = true;
            continue;
        }
        if (strcasecmp (argv[i], "-printstate") == 0) {
            shadow.printstate = true;
            continue;
        }
        if ((strcasecmp (argv[i], "-randmem") == 0) && (loadname == NULL)) {
            oddok = true;
            randmem = true;
            randinit = 14;
            continue;
        }
        if (strcasecmp (argv[i], "-sim") == 0) {
            if ((++ i >= argc) || (argv[i][0] == '-')) {
                fprintf (stderr, "raspictl: missing pipe name after -sim\n");
                return 1;
            }
            simname = argv[i];
            continue;
        }
        if (strcasecmp (argv[i], "-stopat") == 0) {
            if ((++ i >= argc) || (argv[i][0] == '-')) {
                fprintf (stderr, "raspictl: missing address after -stopat\n");
                return 1;
            }
            stopataddr = strtoul (argv[i], &p, 0);
            if ((*p != 0) || (stopataddr > 0xFFFF)) {
                fprintf (stderr, "raspictl: bad -stopat address '%s'\n", argv[i]);
                return 1;
            }
            continue;
        }
        if (strcasecmp (argv[i], "-tclhex") == 0) {
            tclhex = true;
            continue;
        }
        if (argv[i][0] == '-') {
            fprintf (stderr, "raspictl: unknown option %s\n", argv[i]);
            return 1;
        }
        if ((loadname != NULL) || randmem) {
            fprintf (stderr, "raspictl: unknown argument %s\n", argv[i]);
            return 1;
        }

        // hex filename, remainder of command line args available to program
        loadname = argv[i];
        cmdargc  = argc - i;
        cmdargv  = argv + i;
        break;
    }
    if ((loadname == NULL) && ! randmem) {
        fprintf (stderr, "raspictl: missing loadfile parameter\n");
        return 1;
    }

    // read loadfile contents into memory
    if (loadname != NULL) {
        FILE *loadfile = fopen (loadname, "r");
        if (loadfile == NULL) {
            fprintf (stderr, "raspictl: error opening loadfile %s: %m\n", loadname);
            return 1;
        }
        char loadline[144], *p;
        while (fgets (loadline, sizeof loadline, loadfile) != NULL) {
            uint32_t addr = strtoul (loadline, &p, 16);
            if (tclhex) {
                if ((*(p ++) != ' ') || (addr >= sizeof memory) || (addr & 7) || (p[16] != '\n')) goto badload;
                for (int i = 8; -- i >= 0;) {
                    int data = twohexchars (p);
                    if (data < 0) goto badload;
                    memory[addr+i] = data;
                    p += 2;
                }
            } else {
                if (*(p ++) != ':') goto badload;
                while (*p != '\n') {
                    int data = twohexchars (p);
                    if ((data < 0) || (addr >= sizeof memory)) goto badload;
                    memory[addr++] = data;
                    p += 2;
                }
            }
        }
        fclose (loadfile);
        goto goodload;
    badload:;
        fprintf (stderr, "raspictl: bad loadfile line %s", loadline);
        return 1;
    goodload:;
    }

    if (mintimes) {
        pthread_t pid;
        int rc = pthread_create (&pid, NULL, mintimesthread, NULL);
        if (rc != 0) abort ();
        pthread_detach (pid);
    }

    // make sure we undo termios on exit
    signal (SIGHUP,  sighandler);
    signal (SIGINT,  sighandler);
    signal (SIGTERM, sighandler);

    // access cpu circuitry
    // either physical circuit via gpio pins
    // ...or netgen simulator via pipes
    // ...or nothing but shadow
    gpio = (simname != NULL) ? (GpioLib *) new PipeLib (simname) :
                            (nohw ? (GpioLib *) new NohwLib (&shadow) :
                                        (GpioLib *) new PhysLib (cpuhz, ! shadow.chkacid));
    gpio->open ();

    // close gpio on exit
    atexit (exithandler);

    // reset CPU circuit for a couple cycles
    gpio->writegpio (false, G_RESET);
    gpio->halfcycle ();
    gpio->halfcycle ();
    gpio->halfcycle ();

    // tell shadowing that cpu is in reset0 state
    shadow.open (gpio);
    shadow.reset ();

    // drop reset and leave clock signal low
    // enable reading data from cpu
    gpio->writegpio (false, 0);
    gpio->halfcycle ();

    for ever {

        // invariant:
        //  clock has been low for half cycle
        //  G_DENA has been asserted for half cycle so we can read md coming from cpu

        // get input signals just before raising clock
        uint32_t sample = gpio->readgpio ();

        // maybe processor executed an HALT instruction
        if (sample & G_HALT) {

            // -haltstop means just print a message and exit
            if (haltstop) {
                fprintf (stderr, "raspictl: PC=%04X  HALT %04X\n", lastmemread, (sample & G_DATA) / G_DATA0);
                return 0;
            }

            // otherwise wait for an interrupt
            if (! randmem) {
                pthread_mutex_lock (&intreqlock);
                while (intreqreg == 0) {
                    pthread_cond_wait (&intreqcond, &intreqlock);
                }
                pthread_mutex_unlock (&intreqlock);
            }
        }

        // raise clock then wait for half a cycle
        SHADOWCHECK (sample);
        if (shadow.state == Shadow::FETCH2) {
            // keep IR LEDs steady with old opcode instead of turning all on
            // cosmetic only, otherwise can use the else's writegpio()
            gpio->writegpio (true, G_CLK | syncintreq | shadow.ir * G_DATA0);
        } else {
            gpio->writegpio (false, G_CLK | syncintreq);
        }
        gpio->halfcycle ();

        // process the signal sample from just before raising clock
        if (sample & (G_READ | G_WRITE)) {
            if (((sample & (G_WORD | G_DATA0)) == (G_WORD | G_DATA0)) && ! oddok) {
                fprintf (stderr, "raspictl: odd word access %s\n", GpioLib::decocon (CON_G, sample).c_str ());
                dumpregs ();
                abort ();
            }

            uint16_t addr = sample / G_DATA0;
            uint32_t mi = addr / 2 - MAGIC / 2;

            if (addr == stopataddr) {
                fprintf (stderr, "raspictl: stopat %04X; PC %04X\n", addr, shadow.regs[7]);
                return 2;
            }

            if (sample & G_READ) {
                readcounts[addr/2] ++;
                lastmemread = addr;
                uint16_t data;
                if (randmem) {
                    if ((randinit > 0) && (-- randinit & 1)) {
                        data = 0xC000 | ((randinit - 1) << (REGD - 1)) | (7 << REGA);
                    } else if (shadow.state == Shadow::FETCH2) {
                        data = randopcode ();
                    } else {
                        data = randuint16 ();
                    }
                } else if (mi < sizeof magicreaders / sizeof magicreaders[0]) {
                    MagicReader *mr = magicreaders[mi];
                    data = (*mr) (sample);
                } else {
                    data = memory[addr];
                    if (sample & G_WORD) {
                        data |= ((uint16_t) memory[addr^1]) << 8;
                    }
                }
                senddata (data);
            }

            if (sample & G_WRITE) {
                uint16_t data = recvdata ();
                if (randmem) {
                    intreqreg = (randuint16 () & 1) * IRQ_RANDMEM;
                } else {
                    if (mi < sizeof magicwriters / sizeof magicwriters[0]) {
                        MagicWriter *mw = magicwriters[mi];
                        (*mw) (sample, data);
                    } else {
                        if (((addr ^ watchwrite) & -2) == 0) {
                            fprintf (stderr, "raspictl: watch write addr %04X data %04X\n", addr, data);
                            dumpregs ();
                        }
                        if (addr < readonlysize) {
                            fprintf (stderr, "raspictl: write addr %04X below rosize %04X\n", addr, readonlysize);
                            dumpregs ();
                            abort ();
                        }
                        memory[addr] = data;
                        if (sample & G_WORD) {
                            memory[addr^1] = data >> 8;
                        }
                    }
                }
            }
        }

        if (shadow.regs[6] < stacklimit) {
            fprintf (stderr, "raspictl: stack pointer %04X below limit %04X\n", shadow.regs[6], stacklimit);
            dumpregs ();
            abort ();
        }

        // update irq pin
        syncintreq = intreqreg ? G_IRQ : 0;

        // drop the clock and enable data bus read
        // then wait half a clock cycle while clock is low
        gpio->writegpio (false, syncintreq);
        gpio->halfcycle ();
    }
}

static int twohexchars (char const *str)
{
    char buf[3], *p;
    buf[0] = str[0];
    buf[1] = str[1];
    buf[2] = 0;
    uint8_t data = strtoul (buf, &p, 16);
    if (p != &buf[2]) return -1;
    return data;
}

// assuming we are in FETCH2, generate random opcode such that all possible next states have equal probability
// do not generate undefined opcode so shadow won't puque
static uint16_t randopcode ()
{
    switch (randuint16 () % 9) {
        case 0: {  // BCC.1
            uint16_t cond = randuint16 () % 15 + 1;
            uint16_t offs = randuint16 () & 0x3FE;
            return 0x0000 | ((cond & 14) << 9) | offs | (cond & 1);
        }
        case 1: {  // ARITH.1
            uint16_t aop = randuint16 () % 14;
            uint16_t adb = randuint16 () & 0x1FF;
            if (aop >=  3) aop ++;
            if (aop >= 11) aop ++;
            return 0x2000 | (adb << 4) | aop;
        }
        case 2: {  // STORE.1
            return 0x4000 | (randuint16 () & 0x3FFF);
        }
        case 3: {  // LDA.1
            return 0x8000 | (randuint16 () & 0x1FFF);
        }
        case 4: {  // LOAD.1
            uint16_t r = randuint16 ();
            bool imm = (r & 7) == 0;
            uint16_t loadop = r / 8 % 3 + 5;
            uint16_t rardofs = imm ? (((randuint16 () & 7) << REGD) | (7 << REGA)) : (randuint16 () & 0x1FFF);
            return (loadop << 13) | rardofs;
        }
        case 5: {   // HALT.1
            return 0x0000 | ((randuint16 () & 7) << REGB);
        }
        case 6: {   // IRET.1
            return 0x0002;
        }
        case 7: {   // WRPS.1
            return 0x0004 | ((randuint16 () & 7) << REGB);
        }
        case 8: {   // RDPS.1
            return 0x0006 | ((randuint16 () & 7) << REGD);
        }
        default: abort ();
    }
}

static uint16_t randuint16 ()
{
    static uint64_t seed = 0x123456789ABCDEF0ULL;

    // https://www.xilinx.com/support/documentation/application_notes/xapp052.pdf
    uint64_t xnor = ~ ((seed >> 63) ^ (seed >> 62) ^ (seed >> 60) ^ (seed >> 59));
    seed = (seed << 1) | (xnor & 1);

    return (uint16_t) seed;
}

static void dumpregs ()
{
    fprintf (stderr, "raspictl:  R0=%04X R1=%04X R2=%04X R3=%04X R4=%04X R5=%04X R6=%04X PC=%04X\n",
            shadow.regs[0], shadow.regs[1], shadow.regs[2], shadow.regs[3],
            shadow.regs[4], shadow.regs[5], shadow.regs[6], shadow.regs[7]);
}

// CPU wrote to syscall magic location
// assume it is a pointer to syscall parameter block
static uint16_t mr_syscall_rc;
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

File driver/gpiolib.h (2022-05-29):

//    Copyright (C) Mike Rieker, Beverly, MA USA
//    www.outerworldapps.com
//
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
//    EXPECT it to FAIL when someone's HeALTh or PROpeRTy is at RISk.
//
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
//    http://www.gnu.org/licenses/gpl-2.0.html
#ifndef _GPIOLIB_H
#define _GPIOLIB_H

#include <signal.h>
#include <stdio.h>
#include <string>

#include <iowkit.h>

#include "miscdefs.h"

struct Shadow;

#define DEFCPUHZ 472000

#define G_CLK         0x4   // GPIO[02]   out: send clock signal to cpu
#define G_RESET       0x8   // GPIO[03]   out: send reset signal to cpu
#define G_DATA    0xFFFF0   // GPIO[19:04] bi:  data bus bits
#define G_IRQ    0x100000   // GPIO[20]   out: send interrupt request to cpu
#define G__QENA  0x200000   // GPIO[21]   out: we are sending data out to cpu
                            //                 voltage must be high on raspi pin to enable G_DATA->MQ
                            //                 since we go through an inverter, this is considered active low
#define G_DENA   0x400000   // GPIO[22]   out: we are receiving data from cpu
                            //                 voltage must be low on raspi pin to enable MD->G_DATA
                            //                 since we go through an inverter, this is considered active high
#define G_WORD   0x800000   // GPIO[23]    in: 1 = cpu wants to transact a word; 0 = byte
#define G_HALT  0x1000000   // GPIO[24]    in: HALT instruction (in state HALT.1)
#define G_READ  0x2000000   // GPIO[25]    in: cpu wants to read from us
#define G_WRITE 0x4000000   // GPIO[26]    in: cpu wants to write to us
#define G_FLAG  0x8000000   // GPIO[27]   out: use for scope sync
#define G_OUTS (G_CLK|G_RESET|G_IRQ|G__QENA|G_DENA|G_FLAG)  // these are always output pins
#define G_INS (G_READ|G_WRITE|G_WORD|G_HALT)                // these are always input pins
#define G_DATA0 (G_DATA & -G_DATA)                          // low-order data pin

// control pins on the C connector as returned by readcon(CON_C)
#define C_IRQ         (1U <<  0)
#define C_PSW_IE      (1U <<  1)
#define C_PSW_BT      (1U <<  2)
#define C_RESET       (1U <<  3)
#define C_CLK2        (1U <<  4)
#define C_MEM_REB     (1U <<  6)
#define C_PSW_ALUWE   (1U <<  7)
#define C_ALU_IRFC    (1U <<  8)
#define C_GPRS_REB    (1U <<  9)
#define C_BMUX_IRBROF (1U << 10)
#define C_GPRS_WED    (1U << 11)
#define C_MEM_READ    (1U << 12)
#define C_PSW_WE      (1U << 13)
#define C_HALT        (1U << 14)
#define C_GPRS_REA    (1U << 15)
#define C_GPRS_RED2B  (1U << 17)
#define C_ALU_BONLY   (1U << 18)
#define C_BMUX_IRLSOF (1U << 19)
#define C__PSW_REB    (1U << 20)
#define C_BMUX_CON__4 (1U << 21)
#define C_MEM_WORD    (1U << 22)
#define C_ALU_ADD     (1U << 23)
#define C_GPRS_WE7    (1U << 24)
#define C_GPRS_REA7   (1U << 25)
#define C_BMUX_CON_2  (1U << 26)
#define C__IR_WE      (1U << 27)
#define C_BMUX_CON_0  (1U << 29)
#define C_MEM_WRITE   (1U << 30)
#define C__PSW_IECLR  (1U << 31)

#define C_FLIP (C__IR_WE | C__PSW_IECLR | C__PSW_REB)
#define C_RAS  (C_CLK2 | C_IRQ | C_RESET)
#define C_SEQ  ( \
    C_ALU_ADD | C_ALU_BONLY | C_ALU_IRFC | \
    C_BMUX_CON_0 | C_BMUX_CON_2 | C_BMUX_CON__4 | C_BMUX_IRBROF | C_BMUX_IRLSOF | \
    C_GPRS_REA | C_GPRS_REA7 | C_GPRS_REB | C_GPRS_RED2B | C_GPRS_WE7 | C_GPRS_WED | \
    C_HALT | C__IR_WE | \
    C_MEM_READ | C_MEM_REB | C_MEM_WORD | C_MEM_WRITE | \
    C_PSW_ALUWE | C_PSW_BT | C_PSW_IE | C__PSW_IECLR | C__PSW_REB | C_PSW_WE)

// extended pins on the D connector as returned by readcon(CON_D)
#define D_DBUS       0xFFFF         // data bits (scrambled)
#define D_RAWCIN     (1U << 16)     // carry into alu[00]
#define D_RAWCMIDI   (1U << 17)     // carry into alu[08]
#define D_RAWCMIDO   (1U << 18)     // carry outof alu[07]
#define D_RAWCOUT    (1U << 19)     // carry outof alu[15]
#define D_RAWVOUT    (1U << 20)     // carry outof alu[14]
#define D_RAWSHRMIDI (1U << 21)     // shift right into alu[07]
#define D_RAWSHRIN   (1U << 22)     // shift right into alu[15]
#define D_RAWSHROUT  (1U << 24)     // shift right outof alu[00]
#define D_RAWSHRMIDO (1U << 25)     // shift right outof alu[08]

// A,C,I,D connectors
#define CONLETS "ACIDG"
enum IOW56Con {
    CON_A = 0,
    CON_C = 1,
    CON_I = 2,
    CON_D = 3,
    CON_G = 4
};
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

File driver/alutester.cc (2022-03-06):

//    Copyright (C) Mike Rieker, Beverly, MA USA
//    www.outerworldapps.com
//
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
//    EXPECT it to FAIL when someone's HeALTh or PROpeRTy is at RISk.
//
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
//    http://www.gnu.org/licenses/gpl-2.0.html
/**
 * Program runs on any computer to test a physical alu board.
 * Requires four IOW56Paddles connected to the A,C,I,D connectors.
 * sudo insmod km/enabtsc.ko
 * sudo ./alutester -cpuhz 200 -loop {lo,hi} -pauseonerror

    what we send to ALU board:

            hi          lo
        abus[15:08] abus[07:00]
        bbus[15:08] bbus[07:00]
        rawcmid     rawcin
        rawshrin    rawshrmid

                both
            irbus[03:00]
            alu_add
            alu_irfc
            alu_bonly

    what we get from ALU board:

            hi          lo
        dbus[15:08] dbus[07:00]
        rawcout     rawcmid
        rawvout
        rawshrout   rawshrmid
 */

#include <errno.h>
#include <fcntl.h>
#include <sched.h>
#include <stdio.h>
#include <stdlib.h>
#include <string.h>
#include <sys/mman.h>
#include <sys/time.h>
#include <time.h>
#include <unistd.h>

#include "alu8.h"
#include "disassemble.h"
#include "gpiolib.h"
#include "miscdefs.h"

static bool pauseonerror;
static char const *lohi;
static GpioLib *gpio;

static void writeacon (uint16_t abus, uint16_t bbus);
static void writeccon (uint32_t pins);
static void writeicon (uint16_t irbus);
static void writedcon (uint32_t pins);
static uint32_t readdcon ();
static void dopause ();

int main (int argc, char **argv)
{
    bool loopit = false;
    uint32_t cpuhz = DEFCPUHZ;

    setlinebuf (stdout);

    for (int i = 0; ++ i < argc;) {
        if (strcasecmp (argv[i], "-cpuhz") == 0) {
            if (++ i >= argc) {
                fprintf (stderr, "-cpuhz missing freq\n");
                return 1;
            }
            cpuhz = atoi (argv[i]);
            continue;
        }
        if (strcasecmp (argv[i], "-loop") == 0) {
            loopit = true;
            continue;
        }
        if (strcasecmp (argv[i], "-pauseonerror") == 0) {
            pauseonerror = true;
            continue;
        }
        if (argv[i][0] == '-') {
            fprintf (stderr, "unknown option %s\n", argv[i]);
            return 1;
        }
        if (lohi != NULL) {
            fprintf (stderr, "unknown argument %s\n", argv[i]);
            return 1;
        }
        lohi = argv[i];
    }
    if ((lohi == NULL) || ((strcasecmp (lohi, "lo") != 0) && (strcasecmp (lohi, "hi") != 0))) {
        fprintf (stderr, "missing or bad lo/hi argument\n");
        return 1;
    }

    // access seqboard circuitry via paddles
    gpio = new PhysLib (cpuhz);
    gpio->open ();

    srand (0);

    int count  = 0;
    int errors = 0;
    int passno = 0;

    do {

        for (int iter = 0; iter < 1000; iter ++) {

            // make up some random operands
            int randno = rand ();
            uint16_t ir = randno;
            int op = (randno >> 16) & 7;
            uint32_t ctlpins;
            switch (op) {
                case 0:  ctlpins = C_ALU_ADD;   break;
                case 1:  ctlpins = C_ALU_BONLY; break;
                default: ctlpins = C_ALU_IRFC;  break;
            }
            uint16_t abus  = rand ();
            uint16_t bbus  = rand ();
            uint32_t dpins = rand ();

            // send random numbers to board
            writeacon (abus, bbus);     // two 16-bit numbers
            writeccon (ctlpins);        // one of ADD,BONLY,IRFC
            writeicon (ir);             // only [03:00] matter
            writedcon (dpins);          // random carry inputs (lo: RAWCIN,RAWSHRMIDI; hi: RAWCMIDI,RAWSHRIN)

            // let it soak through circuits
            // board is all combinational so no clocking needed
            gpio->halfcycle ();

            // get the 8-bit operands the board should be operating on
            ALU8 alu;
            if (lohi[0] & 4) {
                alu.ain   = abus;
                alu.bin   = bbus;
                alu.cin   = (dpins & D_RAWCIN)     != 0;
                alu.shrin = (dpins & D_RAWSHRMIDI) != 0;
            } else {
                alu.ain   = abus >> 8;
                alu.bin   = bbus >> 8;
                alu.cin   = (dpins & D_RAWCMIDI)   != 0;
                alu.shrin = (dpins & D_RAWSHRIN)   != 0;
            }
            alu.ctlpins = ctlpins;
            alu.ir      = ir;

            // do the 8-bit arithmetic that the board should be doing
            alu.compute ();

            // read what the board is outputting
            uint32_t dconis = readdcon ();
            uint16_t dbusis = GpioLib::dbussort (dconis);

            // compare the two values
            count ++;
            uint8_t doutis;
            bool coutis, voutis, shroutis, ok;
            if (lohi[0] & 4) {
                doutis   = dbusis;
                coutis   = (dconis / D_RAWCMIDO) & 1;
                voutis   = alu.vout;
                shroutis = (dconis / D_RAWSHROUT) & 1;

                ok = (doutis == alu.dout) && (coutis == alu.cout) && (shroutis == alu.shrout);
                if (! ok) errors ++;

                char astr[5];
                astr[0] = 0;
                if (alu.aena) sprintf (astr, "--%02X", alu.ain);

                printf ("%5d.%7d  %d %4s %c %c --%02X %d  =  %d --%02X %d  sb  %d --%02X %d  %s\n",
                        errors, count, alu.shrin, astr, alu.opchar, (alu.bnot ? '~' : ' '),
                        alu.bin, alu.cin,  coutis, doutis, shroutis,  alu.cout, alu.dout, alu.shrout,
                        ok ? "OK" : "BAD");
            } else {
                doutis   = dbusis >> 8;
                coutis   = (dconis / D_RAWCOUT) & 1;
                voutis   = (dconis / D_RAWVOUT) & 1;
                shroutis = (dconis / D_RAWSHRMIDO) & 1;

                ok = (doutis == alu.dout) && (coutis == alu.cout) && (voutis == alu.vout) && (shroutis == alu.shrout);
                if (! ok) errors ++;

                char astr[5];
                astr[0] = 0;
                if (alu.aena) sprintf (astr, "%02X--", alu.ain);

                printf ("%5d.%7d  %d %4s %c %c %02X-- %d  =  %d %d %02X-- %d  sb  %d %d %02X-- %d  %s\n",
                        errors, count, alu.shrin, astr, alu.opchar, (alu.bnot ? '~' : ' '),
                        alu.bin, alu.cin,  coutis, voutis, doutis, shroutis,  alu.cout, alu.vout, alu.dout, alu.shrout,
                        ok ? "OK" : "BAD");
            }
            if (! ok && pauseonerror) {
                dopause ();
            }
        }

        // all done
        time_t nowbin = time (NULL);
        printf ("ERRORS %5d / PASS %d  %s\n", errors, ++ passno, ctime (&nowbin));

        // maybe keep doing it
    } while (loopit);

    return 0;
}

static void writeacon (uint16_t abus, uint16_t bbus)
{
    uint32_t pins = GpioLib::abusshuf (abus) | GpioLib::bbusshuf (bbus);
    if (! gpio->writecon (CON_A, 0xFFFFFFFF, pins)) {
        abort ();
    }
}
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

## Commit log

2022-03-06 initial release
    [120mmfan.FCStd, IOW56Paddle.kicad_pcb, IOW56Paddle.sch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]
2022-03-15 bunch of new runtime library stuff plus some small compiler fixes
    assembler not barf on long compiler source lines
    define symbol __HODE__ in preprocessor
    handle compiling 1.0/0.0 as a NAN
    make sure testprim gets value in range
    check for finally duplicate label prim optimized out
    optimize anding a larger int size with a smaller int size to give smaller int size
    fix shifting quadword right when shifting at least 16 bits
    fix null pointer crash in printf() & related
    add fabs[f](), conversion byte<->float,double, some trig & exponent functions, strto[d/f]()
    update circus sample app to read circuit parameters from stdin instead of programming them
    [raspictl.cc]
2022-03-25 some compiler and runtime fixes
    compiler fixes
    - fix outputting multiple vtable copies
    - compile script work from any directory and allow multiple source files
    - "and" of two ints result is size of smaller int
    - arith on two small int constants needing bigger result size
    - fix some null pointer crashes after reporting errors
    move crtl source into crtl/library directory
    - and split into smaller files for better selective linking
    - add readline and some math functions
    - calc - calculator app
    [altr314.cc, gpiolib.h, physlib.cc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]
2022-04-02 various updates
    fix not linking unreferenced library modules
    fix compiling ? : numerics of different sizes
    write calculator input/output to log file calc.log
    add degree/radian selection in calculator
    change one-liner stdio functions to macros
    complex trancendental functions with imag=0 use real-only funcs where possible
    speed up math log() function
    readline handle arrow keys & fix some line editing, also handle ^C, ^Z
    fix sprintf() return value
    add 'a' mode support to fopen()
    update goodpcbs rasboard, regboard
    ParsePCB just compare net names not numbers cuz freeroute renumbers networks
    [raspictl.cc]
2022-05-29 add de0 implementation and some small fixes
    add de0-nano fpga implementation
    calc program:
    * fix mem leak
    * add @ operator to enter complex numbers as magnitude @ angle
    c runtime:
    * add getnowns(), gmtime(), gmtime_r(), time(), timegm()
    * better decoding of fopen() mode string
    * add __div_www, __mod_www, __mul_LWL, __mul_www
    driver:
    * support raspi zero (armv6l)
    * -cpuhz 0 means run as fast as possible (for use with de0)
    * flock /dev/gpiomem so can't run two instances at same time
    [de0raspi.kicad_pcb, de0raspi.sch]
2022-06-16 three small fixes
    load, save commands for crtl/calc demo program
    fix driver/raspictl script running from other directories
    update readme with de0 nano info and other little fixes

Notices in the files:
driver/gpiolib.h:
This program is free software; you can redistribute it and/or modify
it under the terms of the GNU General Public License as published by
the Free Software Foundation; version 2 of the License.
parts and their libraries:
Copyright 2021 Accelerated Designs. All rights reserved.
